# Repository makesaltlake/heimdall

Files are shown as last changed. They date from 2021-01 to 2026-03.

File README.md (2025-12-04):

# Heimdall

Heimdall is [Make Salt Lake](https://makesaltlake.org)'s member management and access control system. It consists of a few different parts:

  - [Firmware](firmware) intended to run on an [ESP32](https://en.wikipedia.org/wiki/ESP32), one per door or other device that needs access control.
  - [PCB designs](hardware) that can be used to make the physical badge readers.

### 
Join [Make Salt Lake's Slack team](https://slack.makesaltlake.org/), then head over to [#rfid-strikeforce](https://app.slack.com/client/T16JZCGBY/CGDLBCCCT) if you'd like to get in touch.

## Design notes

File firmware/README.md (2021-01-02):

ESP32 based 13.56 MHz RFID access control system
===

Components
---
See the KiCad schematics in [boards/inside_board](/boards/inside_board) and [boards/outside_board](/boards/outside_board) for the components required.<br>
The RFID reader/writer module the outside board interfaces to is the [CLEV6630ARD](https://www.nxp.com/design/development-boards/freedom-development-boards/mcu-boards/clev6630ard-nfc-frontend-clrc663-iplus-i-arduino-interface-board:BLE-NFC).

Connection Details
---

The card reader (i.e. door/machinery control) doesn't use the level converter or LCD.<br>
The card writer (i.e. badge programmer) doesn't use the LEDs, buzzer, resistors or relay.

Building
--------

Install the ESP-IDF by following the steps at https://docs.espressif.com/projects/esp-idf/en/release-v4.2/get-started/index.html#installation-step-by-step .
If you clone the esp-idf repository via Git, you should checkout the version with tag `v4.2`.

Once installed, set up your environment by running `. export.sh` (`export.bat` on Windows). Then, you can run `idf.py menuconfig` to configure the BSP (Board Support Package, or `idf.py build` to build the project.

You can upload the build to the ESP32 by running `idf.py flash`, or later `idf.py app-flash` to save the second flashing the bootloader.
To write the NVS data to flash, first edit nvs\_data.csv to fill in your WiFi SSID, WiFi password, URL, RFID Reader API key, RFID Writer API key, and the Tag Key. Then, run `gen_nvs_part.sh` (`gen_nvs_part.cmd` on Windows) to generate the binary file, followed by `write_nvs_part.sh` (`write_nvs_part.cmd` on Windows) to write that file to flash.

Run `idf.py monitor` to cause the ESP32 to reset and attach the serial console.

You can combine steps: for example `idf.py app-flash monitor` to flash the code then monitor the output.

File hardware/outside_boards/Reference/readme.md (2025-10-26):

# Reference Docs

## Antenna Design

The [NXP Antenna Tool](https://community.nxp.com/t5/NFC/bd-p/nfc) was used to
identify the component values and antenna circuit design.

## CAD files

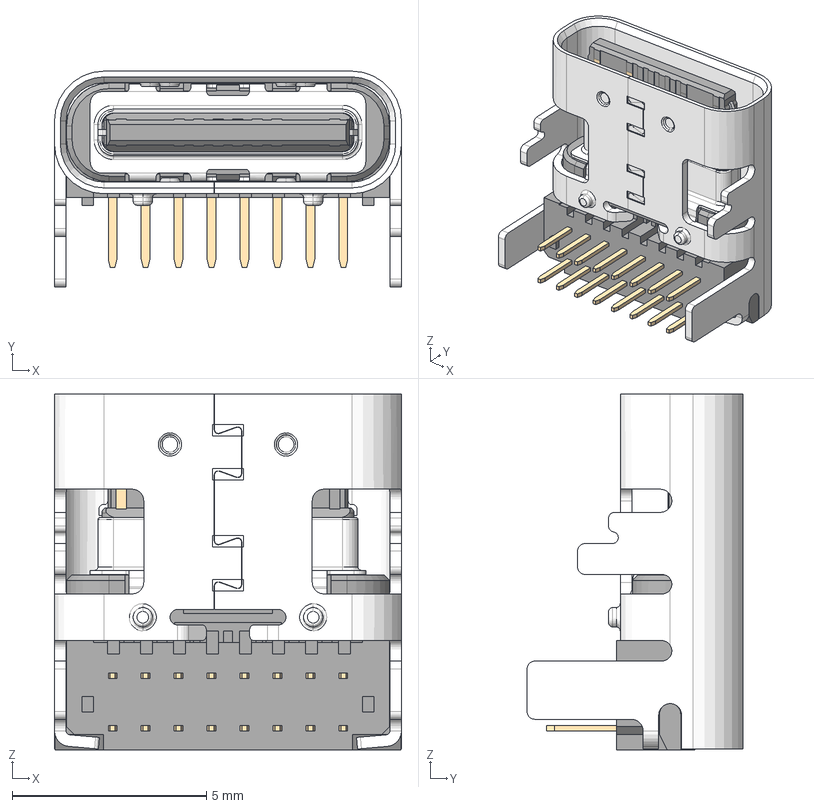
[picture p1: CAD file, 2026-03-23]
hardware/shared/cots/USB4920-00-A.stp
8.94 x 5.56 x 9.17 mm
USB4920-00-A_PART1
USB4920-00-A_PART2
USB4920-00-A_PART3
USB4920-00-A_PART4

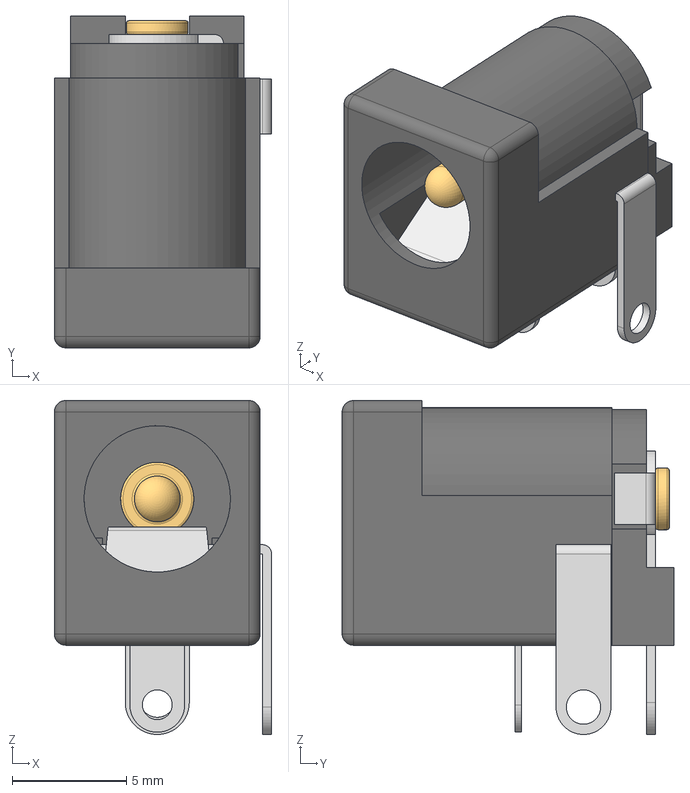
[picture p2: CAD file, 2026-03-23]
hardware/shared/cots/694106301002.stp
9.50 x 14.5 x 14.6 mm
6941xx301002
694106301002_PinContact
6941xx301002_Back
6941xx301002_PinContact2
6941xx301002_PinLame
6941xx301002_PinBis

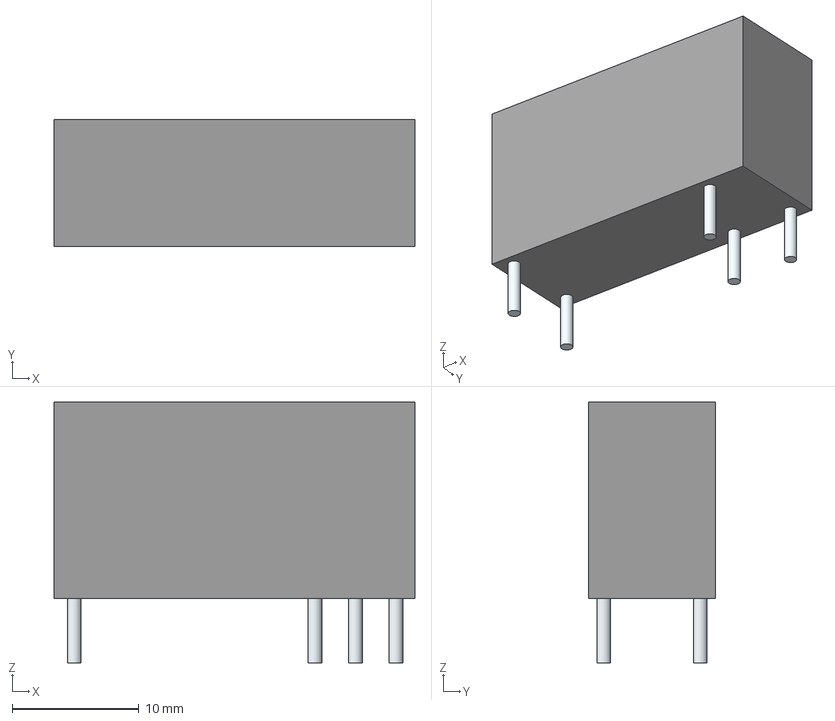
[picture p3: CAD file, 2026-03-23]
hardware/shared/cots/G6RN-17-E-ASI-CF-HA_DC5.stp
28.5 x 10.0 x 20.6 mm
Leads

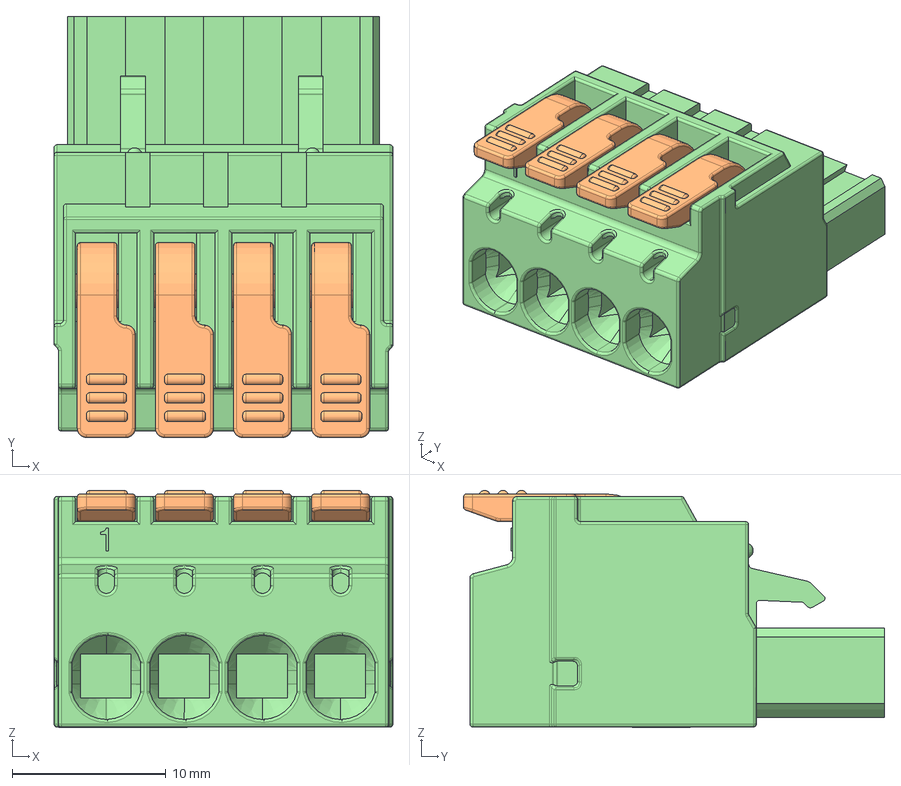
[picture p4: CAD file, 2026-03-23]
hardware/shared/cots/pxc_1110583_08_00_LPC-2-5-4-ST-5-08_3D.stp
22.0 x 27.4 x 15.4 mm

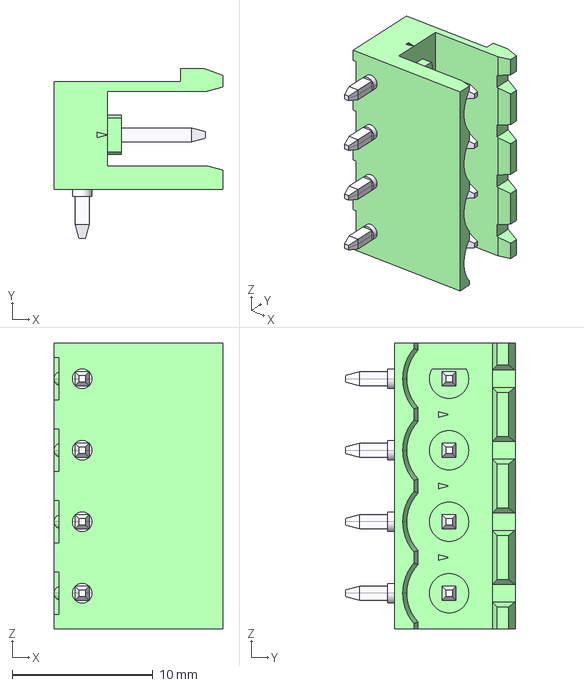
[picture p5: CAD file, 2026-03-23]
hardware/shared/cots/1759033.stp
12.0 x 12.1 x 20.3 mm

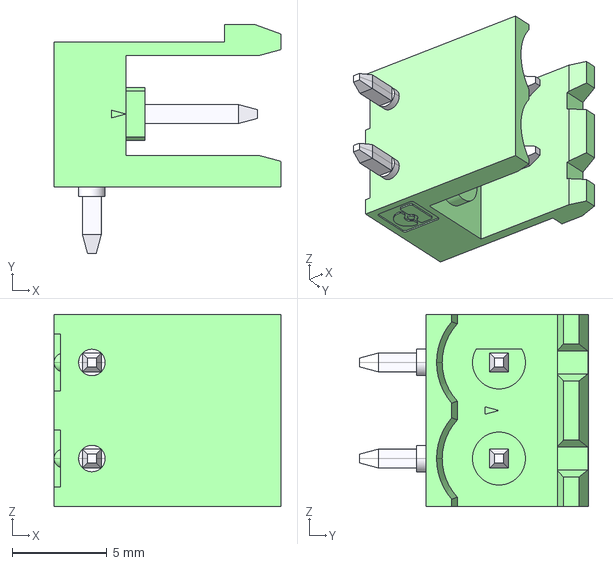
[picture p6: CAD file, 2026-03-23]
hardware/shared/cots/1759017.stp
12.0 x 12.1 x 10.2 mm

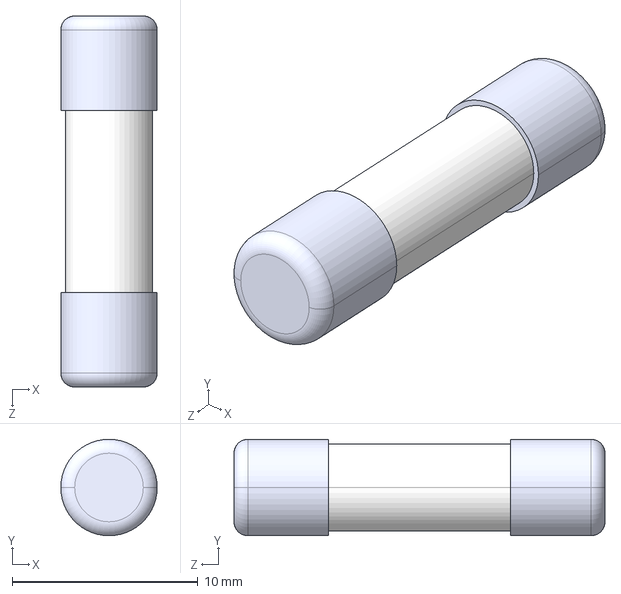
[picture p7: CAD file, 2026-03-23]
hardware/shared/cots/5x20 Fuse.stp
5.20 x 5.20 x 20.0 mm

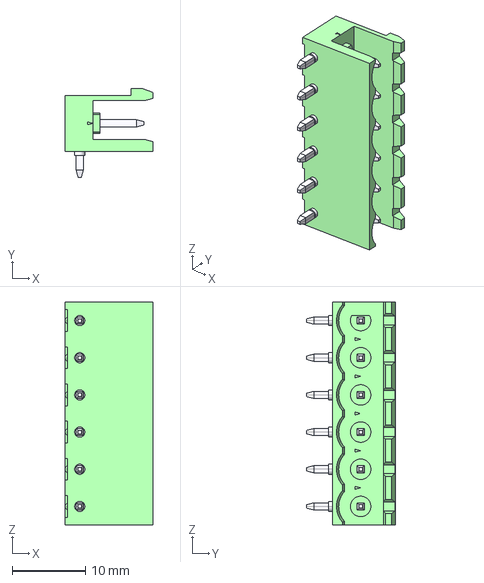
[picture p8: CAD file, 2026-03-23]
hardware/shared/cots/1759059.stp
12.0 x 12.1 x 30.5 mm

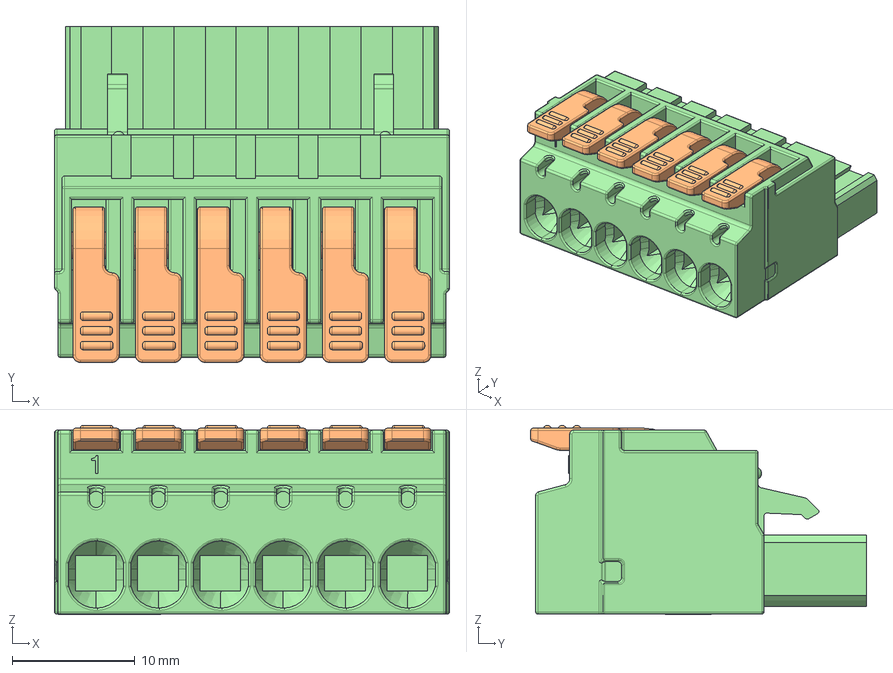
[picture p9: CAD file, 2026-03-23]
hardware/shared/cots/pxc_1110585_10_00_LPC-2-5-6-ST-5-08_3D.stp
32.2 x 27.4 x 15.4 mm

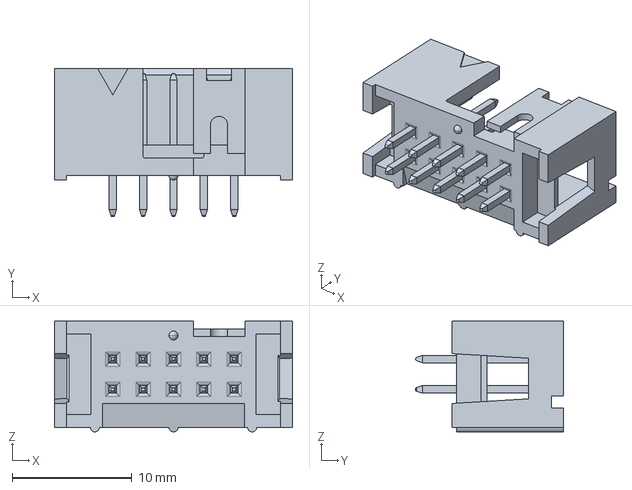
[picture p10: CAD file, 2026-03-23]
hardware/shared/cots/75869-y01c.stp
19.9 x 12.4 x 9.27 mm

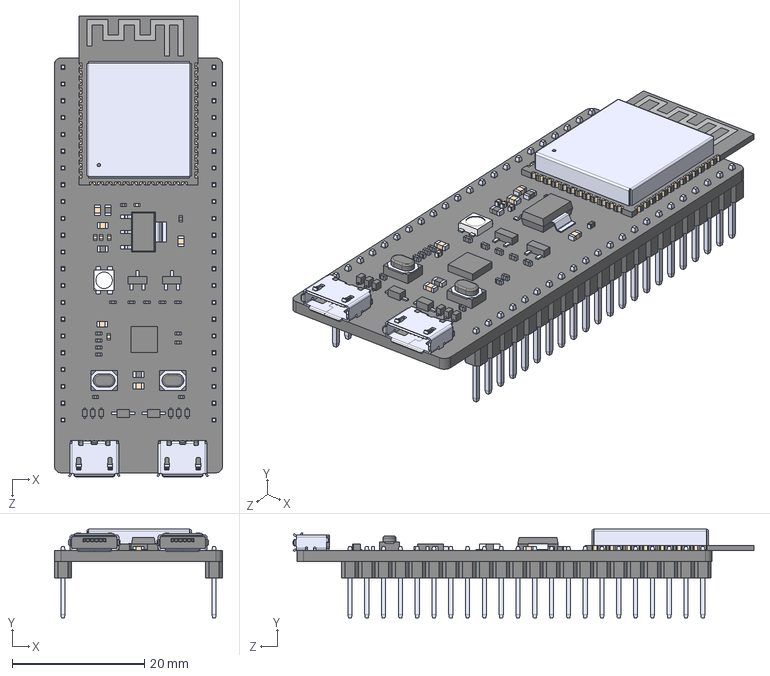
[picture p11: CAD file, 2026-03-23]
hardware/shared/cots/ESP32-S3-DEVKITC-1-N8R8.STEP
25.4 x 13.4 x 69.6 mm

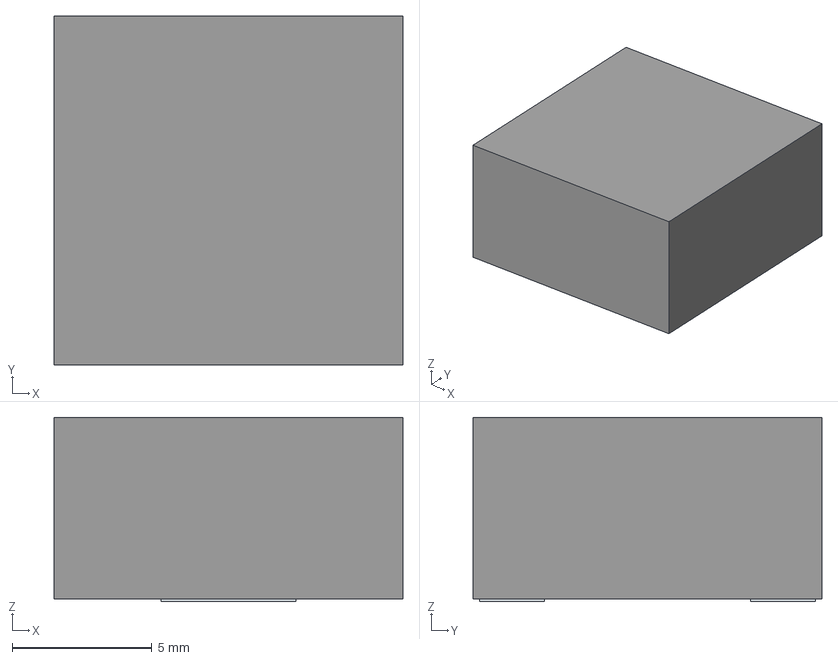
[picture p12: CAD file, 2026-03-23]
hardware/shared/cots/SRR1260A-4R7Y.stp
12.5 x 12.5 x 6.60 mm
Pins

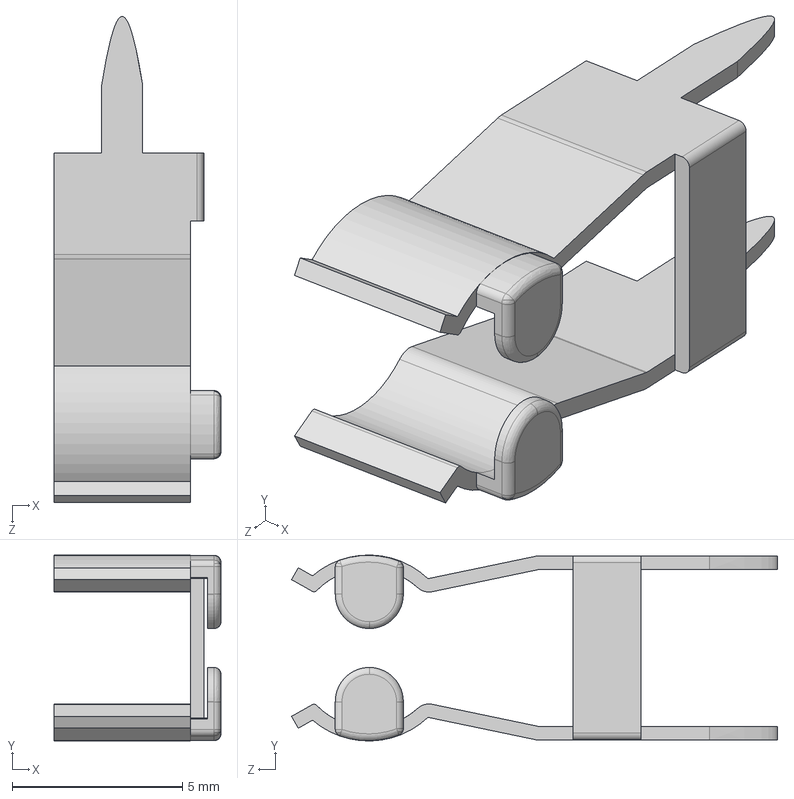
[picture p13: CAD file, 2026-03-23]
hardware/shared/cots/52100001009.stp
4.90 x 5.46 x 14.3 mm

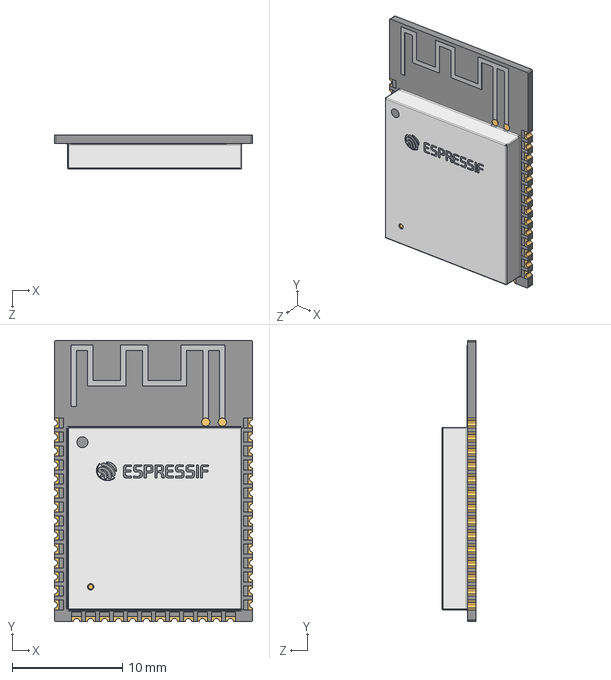
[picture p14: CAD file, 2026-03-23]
hardware/shared/cots/ESP32-S3-WROOM-1-N8R8.stp
18.0 x 25.5 x 3.10 mm

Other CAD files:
hardware/shared/cots/pxc_1110581_10_00_LPC-2-5-2-ST-5-08_3D.stp
hardware/shared/cots/CRJ024-1-TH.stp
hardware/shared/cots/1991095.stp
hardware/shared/cots/CMT-1075-SMT-TR.stp
hardware/shared/cots/43045-1019.stp
hardware/shared/cots/53398-1071.stp
hardware/shared/cots/CLRC66303HNY.stp

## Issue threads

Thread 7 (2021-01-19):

Add a badge reader/writer board firmware system

javawizard, 2021-01-19:
We need a way to allow developers to upload new firmware for the badge readers and writers and allow them to download it over-the-air and update themselves whenever it's changed.

Current thinking is to have that baked into Heimdall itself, probably in the form of something like:

- A new model, `DeviceFirmware`, that has an Active Storage attachment for a binary firmware blob
- Some way of flagging which uploaded firmware should be the current one that gets rolled out to all devices
- Some way of having different sets of firmware for badge readers and badge writers (and other devices in the future)

Open questions:

- Is there any sort of CI pipeline attached to this or is the expectation that a developer builds the firmware on their local computer and uploads it manually to Heimdall?
  - How feasible would a CI pipeline be with Espressif's SDK's requirements?
- How best to support anyone outside of Make Salt Lake who wants to deploy a Heimdall instance? It wouldn't be any good if they had to install Espressif's SDK themselves, build the firmware, and upload it to their own instance. (If CI is feasible, perhaps firmware releases could be built automatically on repo push and Heimdall could pull them in from GitHub and expose them in the UI, with the ability to also upload firmware blobs by hand in case a developer wants to test out some changes they've made locally but haven't pushed.)

bcran, 2021-01-19:
The current expectation is that developers would build the firmware on their local machine and upload it manually. But it _would_ be good to have CI to build it automatically. I'm sure it would be possible to do - I'll look into it.

I like the idea of Heimdall pulling firmware from Github and displaying it in a UI. The initial customization will always have to be locally, since without it the firmware doesn't know the WiFi SSID/password: which brings up the point of what to do if (when?) the WiFi password gets changed? Should we be able to build firmware that has the new password embedded in it, and which updates the non-volatile storage key/pair storage area?

javawizard, 2021-01-19:
@bcran I totally forgot about the WiFi credentials. That throws a wrench in the works...

Is it possible to update the NVS area programmatically from firmware without otherwise replacing the firmware itself? If so, it seems like another way to do it would be to have firmware bundles that don't embed credentials uploaded to GitHub and then have a separate, out-of-band mechanism for pushing new wireless credentials to the devices, like a separate endpoint in Heimdall, since yeah, that totally needs to be specific to a given Heimdall instance. Would that work?

javawizard, 2021-01-19:
(Not that any of this needs to be done right off the bat, of course.)

bcran, 2021-01-24:
@javawizard Yes, the way it's designed is that the NVS area is always updated separately from the firmware, using the esp-idf nvs tool on the host computer. I presume the firmware running on the device can also update that area itself.

I'm guessing we'd need to support having two sets of WiFi credentials, with the old one being tried until the new one starts working?

javawizard, 2021-01-26:
@bcran Yeah, seems like that'd be helpful when doing a switchover. (It's not strictly needed here at the space since our access points can serve multiple SSIDs at the same time, but at least from the Heimdall end it wouldn't be hard to implement.)

So in that case I'll plan to write two different systems, one to expose to badges the WiFi credentials they should use and one to expose the firmware blob they should use.

How do you want to determine if an update is needed? I could write an endpoint to fetch the SHA of the latest firmware bundle - would that be sufficient?

bcran, 2021-01-27:
The firmware has a built-in version number, so I think the ESP-IDF OTA API takes care of it.

javawizard, 2021-01-27:
Got it. Rephrase: is there anything special you'd like me to do to prevent the firmware from needing to download a full copy of the current firmware version every time it checks for an update? (Or, is the firmware small enough that that's not a problem?)

bcran, 2021-01-28:
This may be a little optimistic, but I'm presuming just the first few bytes of the firmware need downloaded to get the firmware description header and check the version.

bcran, 2021-01-28:
Otherwise, the firmware .bin file is only 800 KB, so it wouldn't be terrible if it did download it all.

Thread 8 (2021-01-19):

Spike: membership sign up and management

javawizard, 2021-01-19:
The only thing keeping MSL's WordPress instance (which costs a pretty penny to run, more than  Heimdall itself) around now that the website has been moved to makesaltlake/public_website is that it handles member signup and membership changes (like changing plans and adding card info). That's a lot of money to spend just for that.

I had a look around some time ago at other self-service recurring subscription signup and management portals and all of the options I found were even more expensive at our scale (in no small part because they tend to bill on revenue percentage) or missing features we need (like a way to log in and switch between plans).

So, given all of that and given that a lot of neat possibilities open up if members are able to sign into Heimdall (like certifiers being able to enter certifications themselves instead of Jen having to enter them manually, members being able to purchase gift cards, and Heimdall sending emails to all members certified in a given area when an access code changes), I'd like to try writing a membership signup and management system into Heimdall.

The way I'm thinking that would go down is as follows:

* Write a prototype membership signup form. It should accept all the same fields our current one does and should embed a Stripe credit card field to accept payment. It should create Stripe subscriptions but not do any other functionally useful stuff. It should also use a hardcoded plan.
* Enhance it to use multiple plans - probably hardcode them at first, but perhaps add a DB model where plans can be configured. Whether or not there should be a page to pick between plans is an open question; it may be fine to have the plan chooser live in makesaltlake/public_website and link to a page specific to each plan.
* Enhance it to support coupons. This will require investigating whether Stripe's built-in coupon support is sufficient for our needs (it wasn't for MemberPress, the WordPress plugin we currently use to manage memberships, so they implemented their own coupon system that creates plans from scratch for each new signup; it's possible we may have to do the same).
* See if anything else is missing from the existing membership signup system feature wise
* Ask MSL staff how they want the "where did you hear about us" field to work and if there's any other data they'd want to collect from new members going forward
* Wire up email sending to Heimdall in production using something like Sendgrid, SparkPost, or Mailgun. Now that SparkPost no longer offers their 10,000 emails/month free plan, MailGun's [flex plan](https://www.mailgun.com/pricing/) ($0.80/1,000 emails sent) is probably the cheapest for us considering our low volume (which I imagine will be one email receipt per month to each member, and possibly not even that since Stripe also sends receipts on our behalf).
* Configure the signup form to create users in Heindall on signup and send an email with a link to set up the user's account when created. It should only send that email when a user signs up through the form, not when a user is manually created or automatically created by signing up through the old form. There should, however, be a way to send it manually from the admin console, and it would be ideal if an already-existing user who signed up again through the form (perhaps because they cancelled a while back and are signing up again) got the email as well if they hadn't yet set a password.
* Build a page where an authenticated user can update their Stripe card info on file. It will need to do something useful if they don't have a corresponding Stripe customer yet. It will also need to do something useful if they have multiple Customers in Stripe (and we should see if and how many of such users exist).
* Build a page where an authenticated user can change their plan. We'll need to think through whether they should be able to apply a coupon when they do that (and how to limit most coupons from being used more than once by the same user).
* Build some sort of way for existing members to sign up for a Heimdall account and manage their membership there
* Do a pass through to see if there are any other member management features we need for round 1 that are missing and implement them.
* Try having a few new members we talk to on tours sign up through the new system and see how it goes for them. Make any changes needed based on their feedback.
* (Possibly consider A/B testing the new signup form vs the old one to make sure there isn't a notable decrease in conversions, and make any changes needed to address that if there is)
* Roll out the new system to all new member signups
* Put a note on the old WordPress system directing users to the new system (but leave the old one running for a bit)
* Announce the new system to the membership somewhere
* After some time, sunset the old system and possibly consider moving/aliasing Heimdall to membership.makesaltlake.org

javawizard, 2021-01-19:
One important note: however member signup and management is implemented, it needs to be easy to replace the system with an off-the-shelf system on short notice should all of us developers get hit by a bus (even if it costs more than we'd like). The last thing we want to do is get into a situation where years down the road Heimdall dies, no-one's around to fix it, and we can't sign members up as a result.

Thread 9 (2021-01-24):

Add a way to filter users by those who have a certain discount applied

javawizard, 2021-01-24:
This is per a request from Jen, though I can't find the source at the moment - we would like to be able to view users who have a particular discount applied at the current moment.

This may be tricker than it sounds, because MemberPress creates oneoff Stripe plans for each user and doesn't appear to expose to Stripe which MemberPress-side discount was applied when the user signed up. We may need to talk to MemberPress's API to do that...

...and, given #8, it's debatable whether we should do that now or whether we should wait a bit to see if we're able to do #8 and import all subscriptions, including MemberPress discount data, into Heimdall and save ourselves some trouble.

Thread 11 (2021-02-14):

Switch the Synchrotron reporter to use information from the Subscription model to compute its data

javawizard, 2021-02-14:
That will allow the synchrotron reporter to report instantly without having to iterate through all Stripe subscriptions via Stripe's API each time it's about to post.

It will also make #10 easier to implement since we can detect if the subscription in question already has `unpaid` set to `true` - in which case there's no need to re-notify about a failed payment.

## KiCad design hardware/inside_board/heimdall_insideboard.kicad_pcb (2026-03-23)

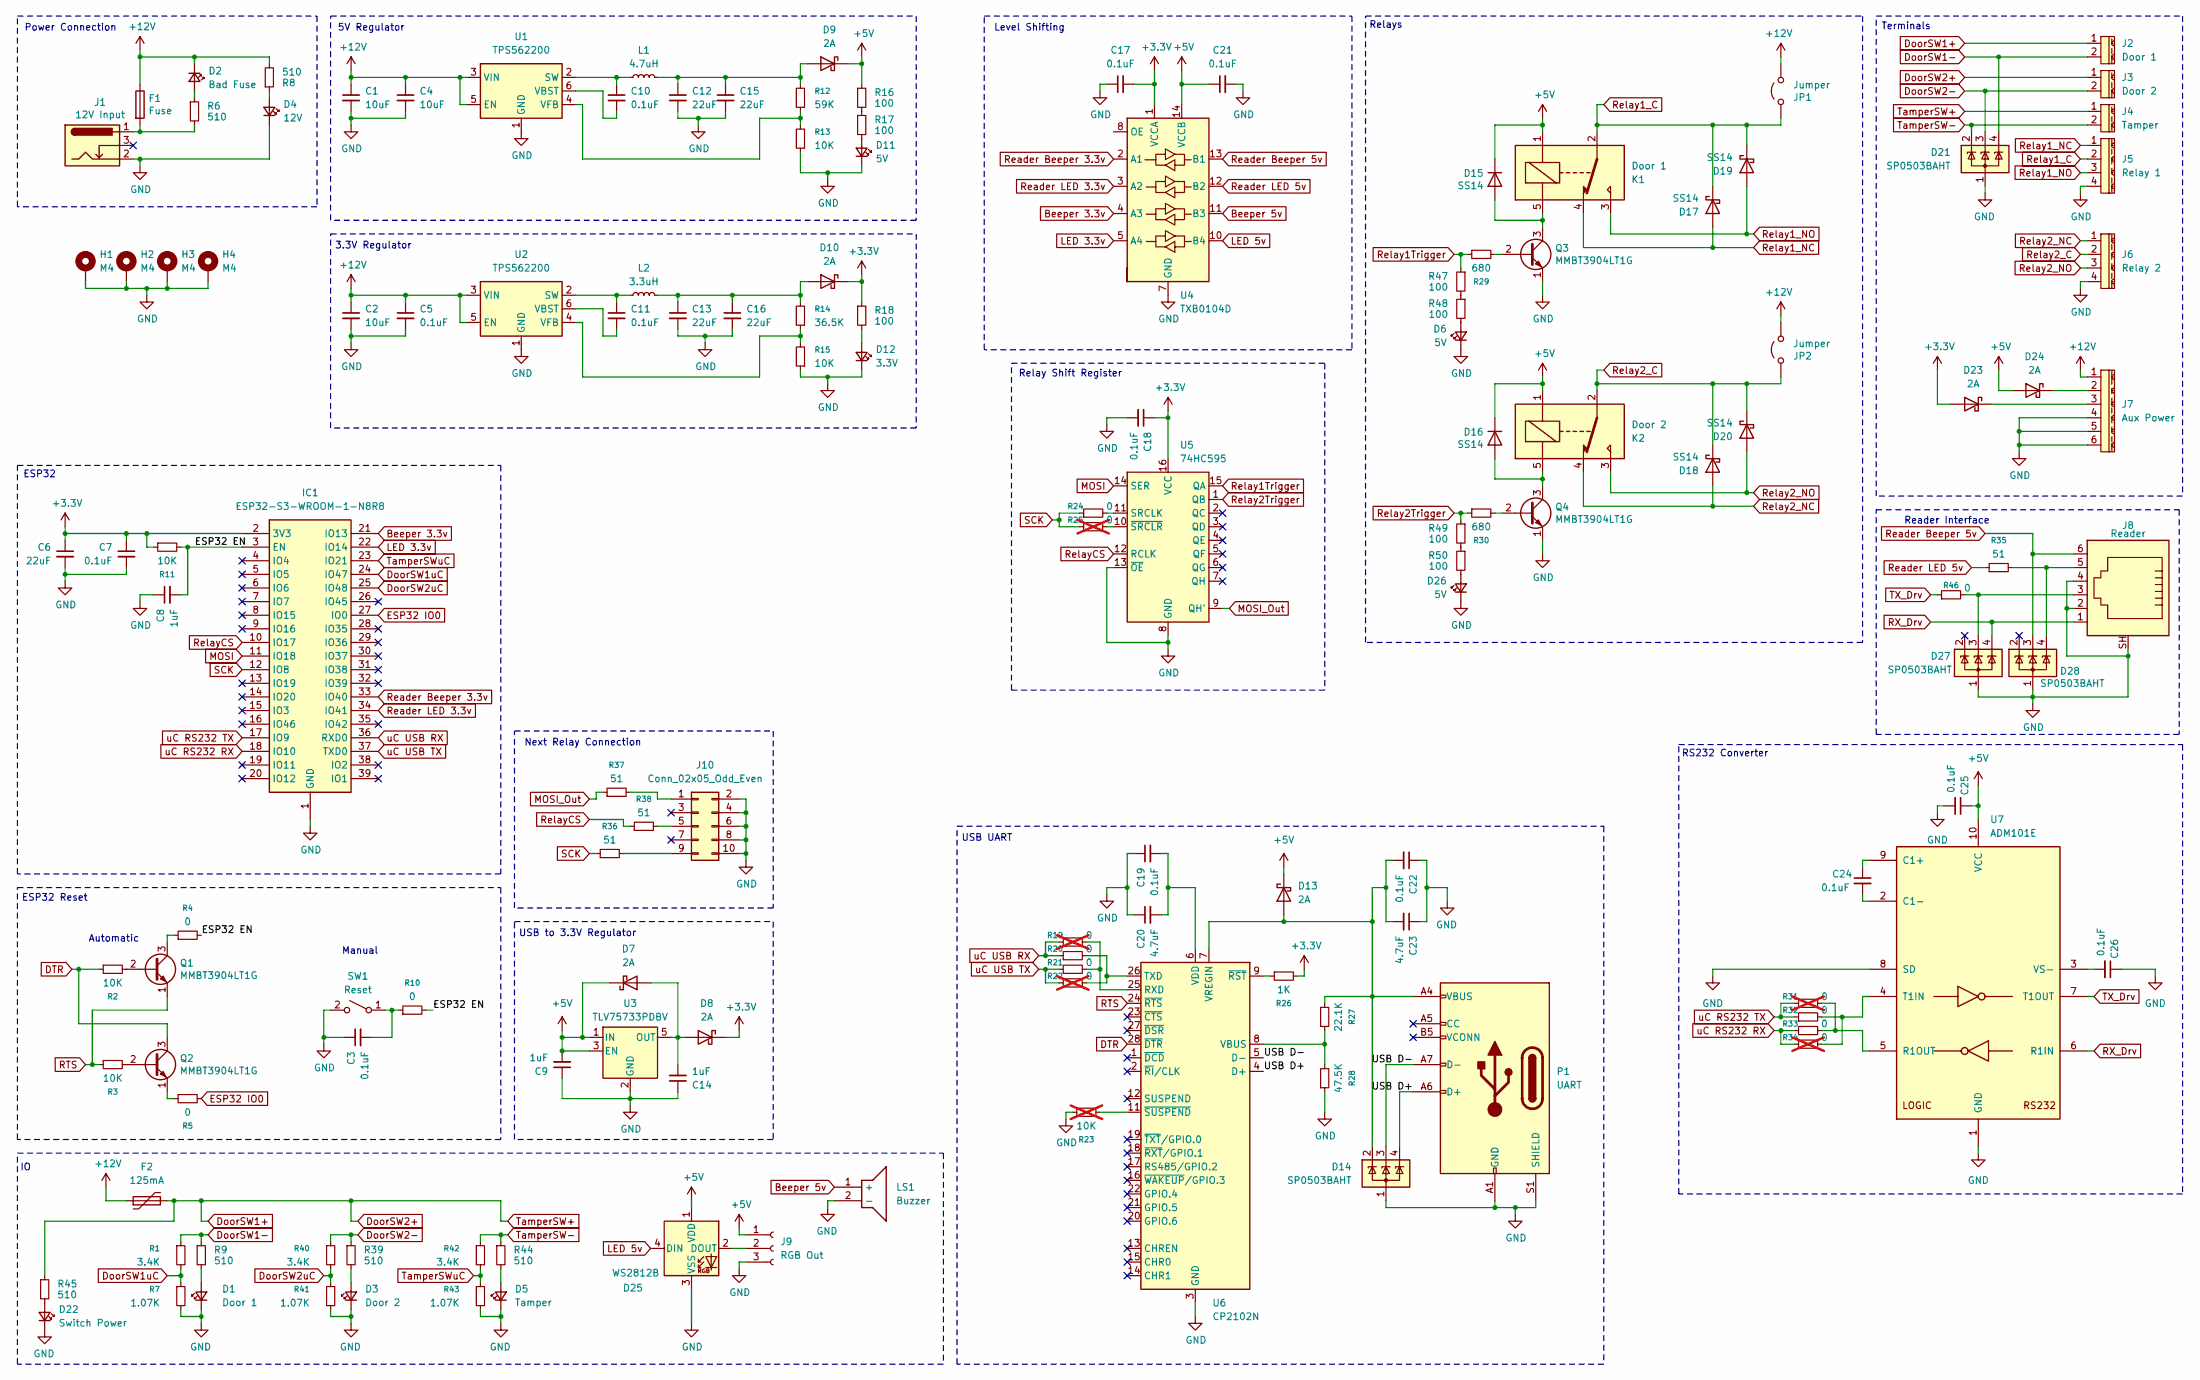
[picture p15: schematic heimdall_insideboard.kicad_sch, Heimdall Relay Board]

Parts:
C1, C2, C4: 10uF; C_0805_2012Metric
C3, C5, C7, C10, C11, C17, C18, C19, C21, C22, C24, C25, C26: 0.1uF; C_0805_2012Metric
C6, C12, C13, C15, C16: 22uF; C_0805_2012Metric
C8, C9, C14: 1uF; C_0805_2012Metric
C20, C23: 4.7uF; C_0805_2012Metric
D1: Door 1; LED_0805_2012Metric
D2: Bad Fuse; LED_0805_2012Metric
D3: Door 2; LED_0805_2012Metric
D4: 12V; LED_0805_2012Metric
D5: Tamper; LED_0805_2012Metric
D6, D11, D26: 5V; LED_0805_2012Metric
D7, D8, D9, D10, D13, D23, D24: 2A; D_SMB
D12: 3.3V; LED_0805_2012Metric
D14, D21, D27, D28: SP0503BAHT; SOT-143
D15, D16, D17, D18, D19, D20: SS14; D_SMA
D22: Switch Power; LED_0805_2012Metric
D25: WS2812B; LED_WS2812B_PLCC4_5.0x5.0mm_P3.2mm
F1: Fuse; Fuseholder_Clip-5x20mm_Littelfuse_521_Lateral_P17.00x5.00mm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
F2: 125mA; Fuse_1206_3216Metric
H1, H2, H3, H4: M4; MountingHole_4.3mm_M4_Pad_Via
IC1: ESP32-S3-WROOM-1-N8R8; ESP32S3WROOM1N8R8; Mouser Part Number 356-EP32S3WROOM1N8R8
J1: 12V Input; BarrelJack_Wuerth_6941xx301002
J2: Door 1; 1759017
J3: Door 2; 1759017
J4: Tamper; 1759017
J5: Relay 1; 1759033
J6: Relay 2; 1759033
J7: Aux Power; 1759059
J8: Reader; CRJ0241TH
J9: RGB Out; PinHeader_1x03_P2.54mm_Vertical
J10: Conn_02x05_Odd_Even; 75869-101LF
JP1, JP2: Jumper; PinHeader_1x03_P2.54mm_Vertical
K1: Door 1; G6RN17EASICFHADC5; Manufacturer_Part_Number G6RN-17-E-ASI-CF-HA DC5
K2: Door 2; G6RN17EASICFHADC5; Manufacturer_Part_Number G6RN-17-E-ASI-CF-HA DC5
L1: 4.7uH; SRR1260A4R7Y
L2: 3.3uH; SRR1260A4R7Y
LS1: Buzzer; CMT1075SMTTR; Mouser Part Number 490-CMT-1075-SMT-TR
P1: UART; USB4920-00-A
Q1, Q2, Q3, Q4: MMBT3904LT1G; SOT-23-3
R1, R40, R42: 3.4K; R_0805_2012Metric
R2, R3, R11, R13, R15: 10K; R_0805_2012Metric
R4, R5, R10, R20, R21, R24, R32, R33, R46: 0; R_0805_2012Metric
R6, R8, R9, R39, R44, R45: 510; R_0805_2012Metric
R7, R41, R43: 1.07K; R_0805_2012Metric
R12: 59K; R_0805_2012Metric
R14: 36.5K; R_0805_2012Metric
R16, R17, R18, R47, R48, R49, R50: 100; R_0805_2012Metric
R19, R22, R25, R31, R34: 0; R_0805_2012Metric; not fitted
R23: 10K; R_0805_2012Metric; not fitted
R26: 1K; R_0805_2012Metric
R27: 22.1K; R_0805_2012Metric
R28: 47.5K; R_0805_2012Metric
R29, R30: 680; R_0805_2012Metric
R35, R36, R37, R38: 51; R_0805_2012Metric
SW1: Reset; SW_SPST_Omron_B3FS-100xP
U1, U2: TPS562200; SOT-23-6
U3: TLV75733PDBV; SOT-23-5
U4: TXB0104D; SOIC-14_3.9x8.7mm_P1.27mm
U5: 74HC595; SOIC-16W_7.5x10.3mm_P1.27mm
U6: CP2102N; QFN-28-1EP_5x5mm_P0.5mm_EP3.35x3.35mm
U7: ADM101E; MSOP-10_3x3mm_P0.5mm

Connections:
+3.3V: C6.1, C7.1, C17.2, C18.1, D8.1 (K), D10.1 (K), D23.2 (A), IC1.2 (3V3), R11.1, R18.1, R26.2, U4.1 (VCCA), U5.16 (VCC)
+5V: C9.2, C21.1, C25.1, D7.1 (K), D9.1 (K), D13.1 (K), D15.1 (K), D16.1 (K), D24.2 (A), D25.1 (VDD), J9.1, K1.1, K2.1, R16.1, U3.1 (IN), U3.3 (EN), U4.14 (VCCB), U7.10 (VCC)
+12V: C1.1, C2.1, C4.1, C5.1, D2.1 (K), F1.1, F2.1, J7.1, JP1.1 (A), JP2.1 (A), R8.2, U1.3 (VIN), U1.5 (EN), U2.3 (VIN), U2.5 (EN)
/ESP32 EN: C8.2, IC1.3 (EN), R4.2, R10.2, R11.2
/USB D+: D14.4 (K), P1.A6 (D+), U6.4 (D+)
/USB D-: D14.3 (K), P1.A7 (D-), U6.5 (D-)
Beeper 3.3v: IC1.21 (IO13), U4.4 (A3)
Beeper 5v: LS1.1 (+), U4.11 (B3)
DTR: Q2.3 (C), R2.1, U6.28 (~DTR)
DoorSW1+: F2.2, J2.1, J3.1, J4.1, R45.1
DoorSW1-: D21.4 (K), J2.2, R1.1, R9.1
DoorSW1uC: IC1.24 (IO47), R1.2, R7.1
DoorSW2-: D21.3 (K), J3.2, R39.1, R40.1
DoorSW2uC: IC1.25 (IO48), R40.2, R41.1
ESP32 IO0: IC1.27 (IO0), R5.2
GND: C1.2, C2.2, C3.1, C4.2, C5.2, C6.2, C7.2, C8.1, C9.1, C12.2, C13.2, C14.1, C15.2, C16.2, C17.1, C18.2, C19.1, C20.1, C21.2, C22.1, C23.1, C25.2, C26.1, D1.1 (K), D3.1 (K), D4.1 (K), D5.1 (K), D6.1 (K), D11.1 (K), D12.1 (K), D14.1 (A), D21.1 (A), D22.1 (K), D25.3 (VSS), D26.1 (K), D27.1 (A), D28.1 (A), H1.1, H2.1, H3.1, H4.1, IC1.1 (GND), J1.2, J5.4, J6.4, J7.4, J7.5, J7.6, J8.2, J8.4, J8.SH, J9.3, J10.2, J10.4, J10.6, J10.8, J10.10, LS1.2 (-), P1.A1 (GND), P1.A12 (GND), P1.B1 (GND), P1.B12 (GND), P1.S1 (SHIELD), Q3.1 (E), Q4.1 (E), R7.2, R13.1, R15.1, R23.1, R28.1, R41.2, R43.2, SW1.2 (B), U1.1 (GND), U2.1 (GND), U3.2 (GND), U4.7 (GND), U5.8 (GND), U5.13 (~OE), U6.3 (GND), U6.29 (GND), U7.1 (GND), U7.8 (SD)
LED 3.3v: IC1.22 (IO14), U4.5 (A4)
LED 5v: D25.4 (DIN), U4.10 (B4)
MOSI: IC1.11 (IO18), U5.14 (SER)
MOSI_Out: R37.1, U5.9 (QH')
unnamed: D1.2 (A), R9.2
unnamed: D2.2 (A), R6.1
unnamed: D3.2 (A), R39.2
unnamed: D4.2 (A), R8.1
unnamed: D5.2 (A), R44.2
unnamed: D6.2 (A), R48.2
unnamed: C14.2, D7.2 (A), D8.2 (A), U3.5 (OUT)
unnamed: C12.1, C15.1, D9.2 (A), L1.2, R12.2
unnamed: C13.1, C16.1, D10.2 (A), L2.2, R14.2
unnamed: D11.2 (A), R17.2
unnamed: D12.2 (A), R18.2
unnamed: C22.2, C23.2, D13.2 (A), D14.2 (K), P1.A4 (VBUS), P1.A9 (VBUS), P1.B4 (VBUS), P1.B9 (VBUS), R27.2, U6.7 (VREGIN)
unnamed: D15.2 (A), K1.5, Q3.3 (C)
unnamed: D16.2 (A), K2.5, Q4.3 (C)
unnamed: D22.2 (A), R45.2
unnamed: D23.1 (K), J7.3
unnamed: D24.1 (K), J7.2
unnamed: D25.2 (DOUT), J9.2
unnamed: D26.2 (A), R50.2
unnamed: D27.3 (K), J8.3, R46.2
unnamed: D28.4 (K), J8.5, R35.2
unnamed: F1.2, J1.1, R6.2
unnamed: J10.1, R37.2
unnamed: J10.5, R38.2
unnamed: J10.9, R36.2
unnamed: Q1.2 (B), R2.2
unnamed: Q1.3 (C), R4.1
unnamed: Q2.2 (B), R3.2
unnamed: Q2.1 (E), R5.1
unnamed: Q3.2 (B), R29.2
unnamed: Q4.2 (B), R30.2
unnamed: R16.2, R17.1
unnamed: R47.2, R48.1
unnamed: R49.2, R50.1
unnamed: C3.2, R10.1, SW1.1 (A)
unnamed: C10.1, L1.1, U1.2 (SW)
unnamed: C10.2, U1.6 (VBST)
unnamed: R12.1, R13.2, U1.4 (VFB)
unnamed: C11.1, L2.1, U2.2 (SW)
unnamed: C11.2, U2.6 (VBST)
unnamed: R14.1, R15.2, U2.4 (VFB)
unnamed: R24.2, U5.11 (SRCLK)
unnamed: R25.2, U5.10 (~SRCLR)
unnamed: R19.2, R21.2, U6.25 (RXD)
unnamed: R20.2, R22.2, U6.26 (TXD)
unnamed: R27.1, R28.2, U6.8 (VBUS)
unnamed: C19.2, C20.2, U6.6 (VDD)
unnamed: R26.1, U6.9 (~RST)
unnamed: R23.2, U6.11 (~SUSPEND)
unnamed: C24.1, U7.9 (C1+)
unnamed: C24.2, U7.2 (C1-)
unnamed: R31.2, R33.2, U7.5 (R1OUT)
unnamed: R32.2, R34.2, U7.4 (T1IN)
unnamed: C26.2, U7.3 (VS-)
RTS: Q1.1 (E), R3.1, U6.24 (~RTS)
RX_Drv: D27.4 (K), J8.1, U7.6 (R1IN)
Reader Beeper 3.3v: IC1.33 (IO40), U4.2 (A1)
Reader Beeper 5v: D28.3 (K), J8.6, U4.13 (B1)
Reader LED 3.3v: IC1.34 (IO41), U4.3 (A2)
Reader LED 5v: R35.1, U4.12 (B2)
Relay1Trigger: R29.1, R47.1, U5.15 (QA)
Relay1_C: D17.1 (K), D19.1 (K), J5.2, JP1.2 (B), K1.2
Relay1_NC: D17.2 (A), J5.1, K1.4
Relay1_NO: D19.2 (A), J5.3, K1.3
Relay2Trigger: R30.1, R49.1, U5.1 (QB)
Relay2_C: D18.1 (K), D20.1 (K), J6.2, JP2.2 (B), K2.2
Relay2_NC: D18.2 (A), J6.1, K2.4
Relay2_NO: D20.2 (A), J6.3, K2.3
RelayCS: IC1.10 (IO17), R38.1, U5.12 (RCLK)
SCK: IC1.12 (IO8), R24.1, R25.1, R36.1
TX_Drv: R46.1, U7.7 (T1OUT)
TamperSW-: D21.2 (K), J4.2, R42.1, R44.1
TamperSWuC: IC1.23 (IO21), R42.2, R43.1
uC RS232 RX: IC1.18 (IO10), R33.1, R34.1
uC RS232 TX: IC1.17 (IO9), R31.1, R32.1
uC USB RX: IC1.36 (RXD0), R19.1, R20.1
uC USB TX: IC1.37 (TXD0), R21.1, R22.1

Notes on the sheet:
Power Connection
Relay Shift Register
Automatic
RS232 Converter
ESP32 Reset
USB to 3.3V Regulator
Terminals
Next Relay Connection
Manual
3.3V Regulator
5V Regulator
Reader Interface
Relays
Level Shifting
USB UART
ESP32

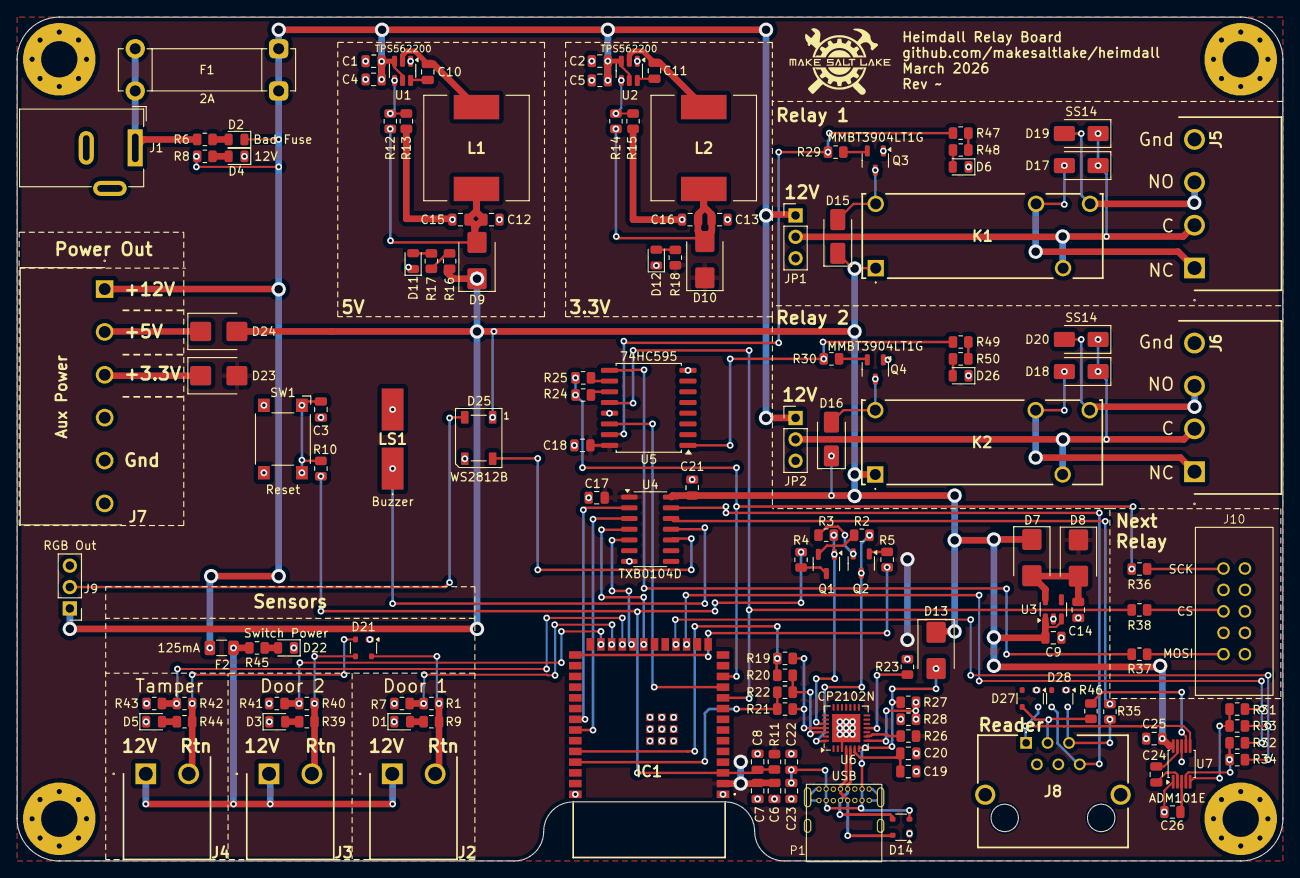
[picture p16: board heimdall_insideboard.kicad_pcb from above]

Board: 2 copper layers, 150.0 x 100.0 mm, 141 parts (0 on the bottom side), 97 nets.

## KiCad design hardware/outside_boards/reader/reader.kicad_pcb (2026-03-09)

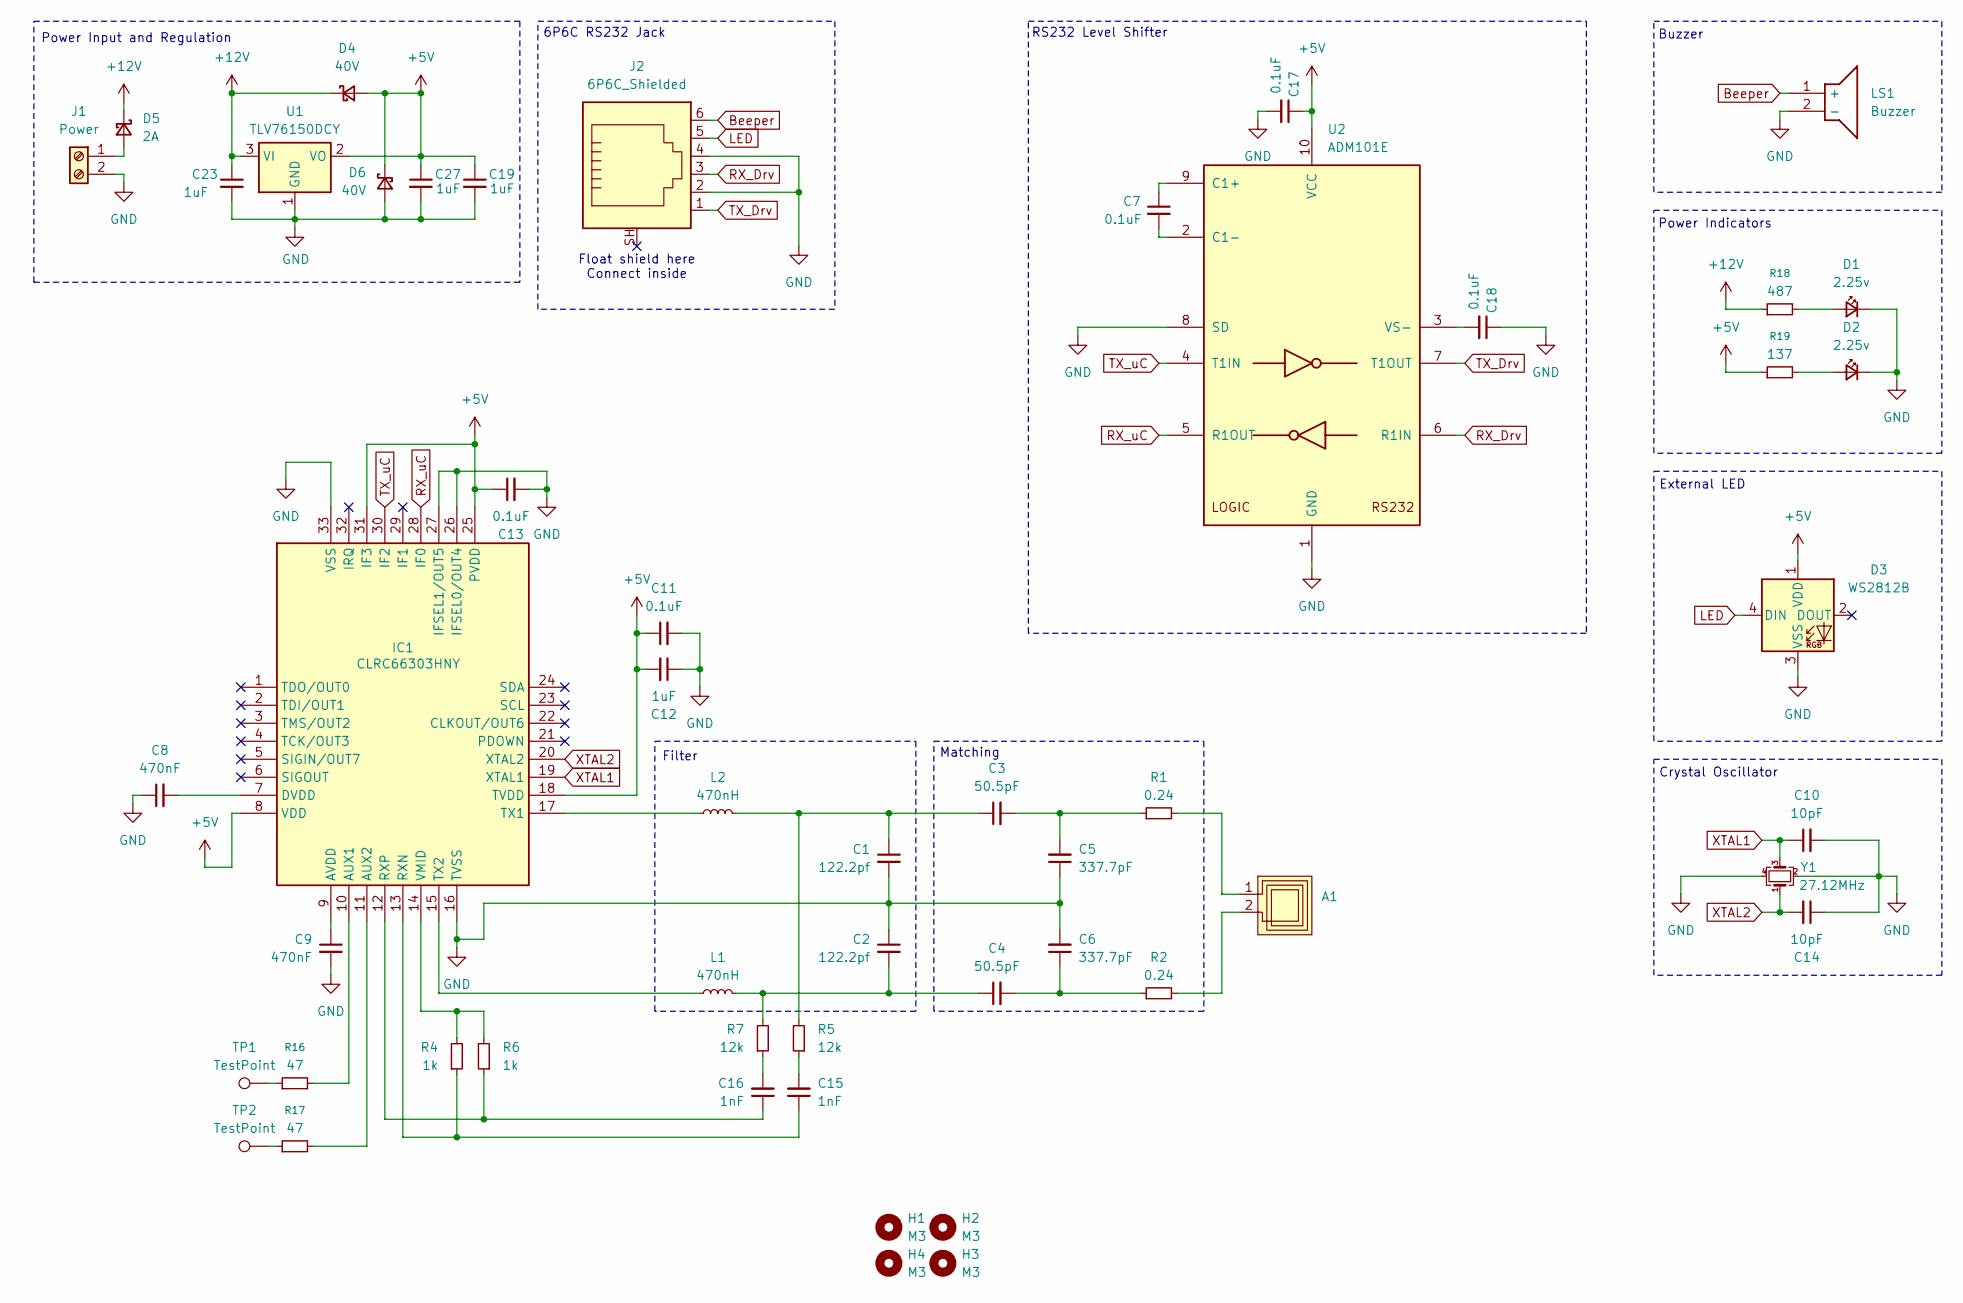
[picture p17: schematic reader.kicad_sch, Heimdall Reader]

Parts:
A1: Anetnna_50x50
C1, C2: 122.2pf; C_0805_2012Metric
C3, C4: 50.5pF; C_0805_2012Metric
C5, C6: 337.7pF; C_0805_2012Metric
C7, C11, C13, C17, C18: 0.1uF; C_0805_2012Metric
C8, C9: 470nF; C_0805_2012Metric
C10, C14: 10pF; C_0805_2012Metric
C12, C19, C23, C27: 1uF; C_0805_2012Metric
C15, C16: 1nF; C_0805_2012Metric
D1, D2: 2.25v; LED_0805_2012Metric
D3: WS2812B; LED_WS2812B_PLCC4_5.0x5.0mm_P3.2mm
D4, D6: 40V; D_1206_3216Metric
D5: 2A; D_1206_3216Metric
H1, H2, H3, H4: M3; MountingHole_3.2mm_M3
IC1: CLRC66303HNY; QFN50P500X500X100-33N; Mouser Part Number 771-CLRC66303HNY
J1: Power; 1991095
J2: 6P6C_Shielded; CRJ0241TH
L1, L2: 470nH; L_0805_2012Metric
LS1: Buzzer; CMT1075SMTTR; Mouser Part Number 490-CMT-1075-SMT-TR
R1, R2: 0.24; R_0805_2012Metric
R4, R6: 1k; R_0805_2012Metric
R5, R7: 12k; R_0805_2012Metric
R16, R17: 47; R_0805_2012Metric
R18: 487; R_0805_2012Metric
R19: 137; R_0805_2012Metric
TP1, TP2: TestPoint; TestPoint_Pad_D1.5mm
U1: TLV76150DCY; SOT-223-3_TabPin2
U2: ADM101E; MSOP-10_3x3mm_P0.5mm
Y1: 27.12MHz; Crystal_SMD_3225-4Pin_3.2x2.5mm

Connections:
+5V: C11.1, C12.2, C13.1, C17.1, C19.1, C27.1, D3.1 (VDD), D4.2 (A), D6.1 (K), IC1.8 (VDD), IC1.18 (TVDD), IC1.25 (PVDD), IC1.31 (IF3), R19.1, U1.2 (VO), U2.10 (VCC)
+12V: C23.1, D4.1 (K), D5.1 (K), R18.1, U1.3 (VI)
Beeper: J2.6, LS1.1 (+)
GND: C1.2, C2.1, C5.1, C6.2, C8.1, C9.2, C10.2, C11.2, C12.1, C13.2, C14.1, C17.2, C18.1, C19.2, C23.2, C27.2, D1.1 (K), D2.1 (K), D3.3 (VSS), D6.2 (A), IC1.16 (TVSS), IC1.26 (IFSEL0/OUT4), IC1.27 (IFSEL1/OUT5), IC1.33 (VSS), J1.2, J2.2, J2.4, LS1.2 (-), U1.1 (GND), U2.1 (GND), U2.8 (SD), Y1.2, Y1.4
LED: D3.4 (DIN), J2.5
unnamed: A1.1, R1.2
unnamed: A1.2, R2.2
unnamed: C1.1, C3.1, L2.2, R5.2
unnamed: C2.2, C4.1, L1.2, R7.2
unnamed: C3.2, C5.2, R1.1
unnamed: C4.2, C6.1, R2.1
unnamed: C15.2, R5.1
unnamed: C16.2, R7.1
unnamed: D1.2 (A), R18.2
unnamed: D2.2 (A), R19.2
unnamed: D5.2 (A), J1.1
unnamed: IC1.10 (AUX1), R16.2
unnamed: IC1.11 (AUX2), R17.2
unnamed: C9.1, IC1.9 (AVDD)
unnamed: C8.2, IC1.7 (DVDD)
unnamed: C15.1, IC1.13 (RXN), R4.1
unnamed: C16.1, IC1.12 (RXP), R6.1
unnamed: IC1.17 (TX1), L2.1
unnamed: IC1.15 (TX2), L1.1
unnamed: IC1.14 (VMID), R4.2, R6.2
unnamed: R16.1, TP1.1
unnamed: R17.1, TP2.1
unnamed: C7.1, U2.9 (C1+)
unnamed: C7.2, U2.2 (C1-)
unnamed: C18.2, U2.3 (VS-)
RX_Drv: J2.3, U2.6 (R1IN)
RX_uC: IC1.28 (IF0), U2.5 (R1OUT)
TX_Drv: J2.1, U2.7 (T1OUT)
TX_uC: IC1.30 (IF2), U2.4 (T1IN)
XTAL1: C10.1, IC1.19 (XTAL1), Y1.3
XTAL2: C14.2, IC1.20 (XTAL2), Y1.1

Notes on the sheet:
External LED
Crystal Oscillator
Power Indicators
Matching
Float shield here Connect inside
Buzzer
6P6C RS232 Jack
Power Input and Regulation
RS232 Level Shifter
Filter

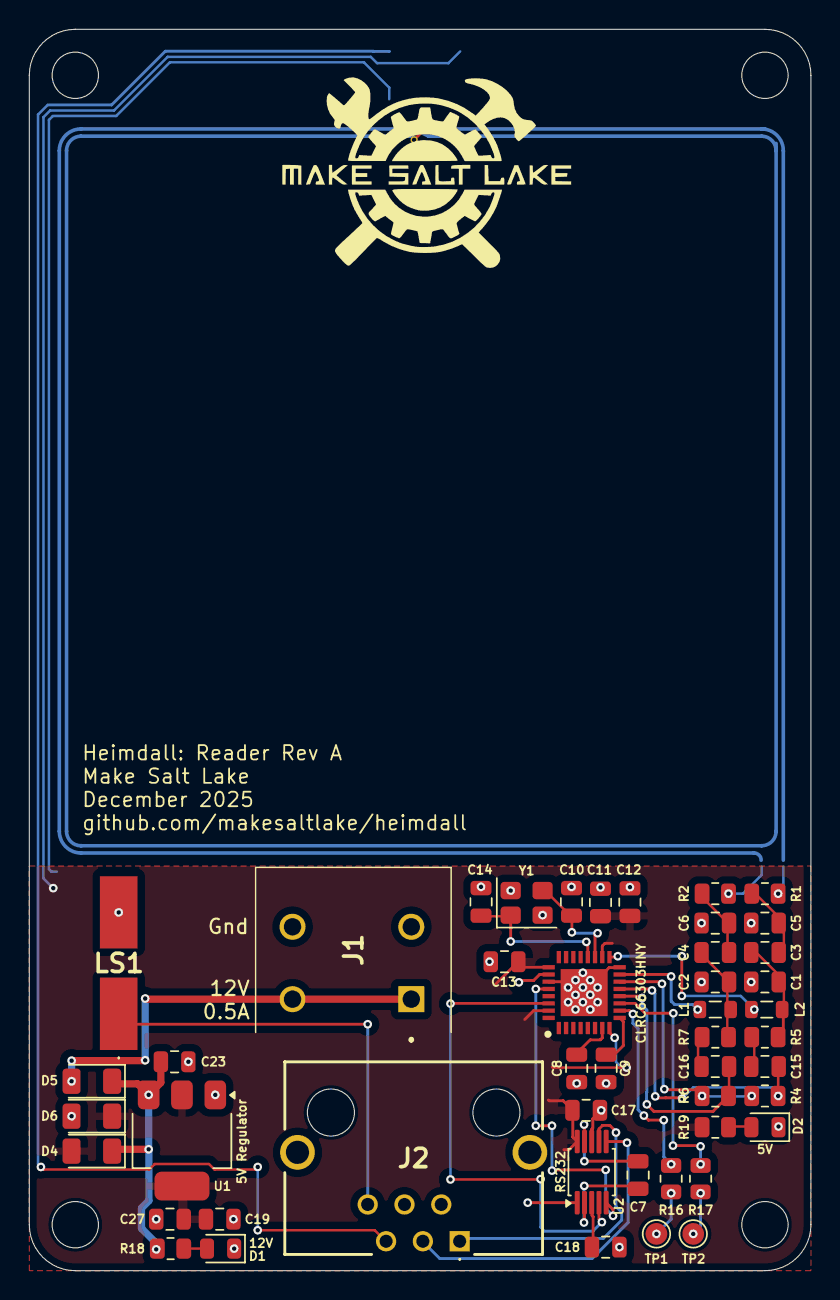
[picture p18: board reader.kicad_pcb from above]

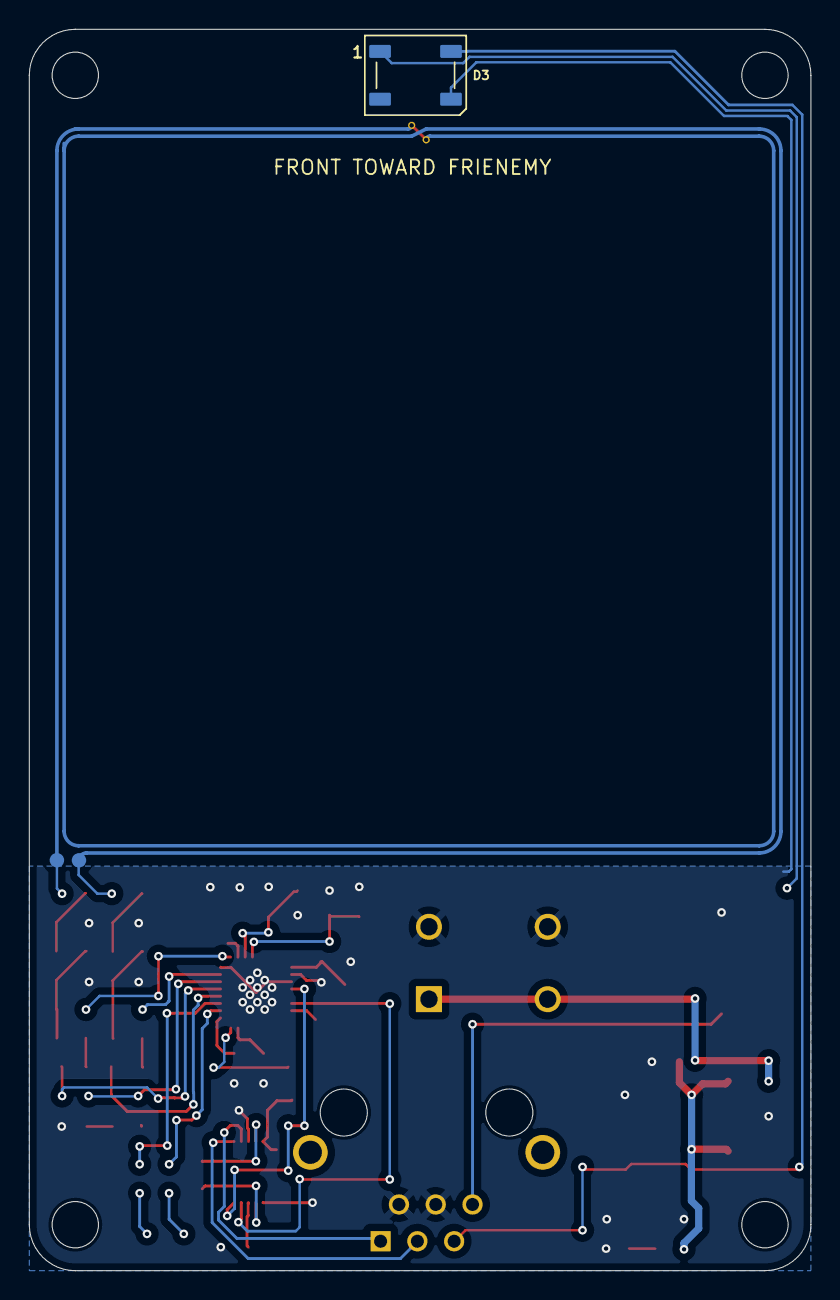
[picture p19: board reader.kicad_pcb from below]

Board: 2 copper layers, 54.0 x 85.7 mm, 53 parts (2 on the bottom side), 36 nets.

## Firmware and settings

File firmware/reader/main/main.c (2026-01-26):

/*
 * Copyright (C) 2020 Rebecca Cran <rebecca@bsdio.com>.
 *
 */

#include <string.h>
#include <unistd.h>
#include <stdio.h>

#include <freertos/FreeRTOS.h>
#include <freertos/task.h>
#include <freertos/event_groups.h>

#include <cJSON.h>
#include <esp_system.h>
#include <esp_event.h>
#include <nvs_flash.h>
#include <esp_log.h>

#include <driver/ledc.h>
#include <soc/ledc_reg.h>
#include <hal/ledc_types.h>

#include <esp_vfs_fat.h>
#include <diskio_wl.h>
#include <esp_vfs.h>

#include "clrc663.h"
#include "iso14443.h"
#include "mifare_classic.h"
#include "tag.h"
#include "network.h"
#include "../ESP32-NeoPixel-WS2812-RMT/ws2812_control.h"


static const char* TAG = "heimdall";

const int LED_GPIO_PIN = 22;
const int BUZZER_GPIO_PIN = 23;
const int RELAY1_GPIO_PIN = 17;
const int RELAY2_GPIO_PIN = 16;
const int RELAY3_GPIO_PIN = 4;
const int TAMPER_SWITCH_GPIO_PIN = 18;

const int RFID_CS_GPIO_PIN = 32;
const int CAM_CS_GPIO_PIN = 15;

extern char *heimdall_host;
extern char *reader_api_key;
extern char *writer_api_key;

char *tag_key = NULL;

cJSON *access_list = NULL;

extern char *wifi_ssid;
extern char *wifi_password;

static void set_buzzer_duty(uint32_t duty)
{
    ledc_set_duty(LEDC_LOW_SPEED_MODE, LEDC_CHANNEL_0, duty);
    ledc_update_duty(LEDC_LOW_SPEED_MODE, LEDC_CHANNEL_0);
}

static void heimdall_setup_buzzer(void)
{
    // Configure the buzzer
//    const ledc_timer_config_t buzzer_timer = {LEDC_LOW_SPEED_MODE, {LEDC_TIMER_10_BIT}, LEDC_TIMER_0, 2670, LEDC_AUTO_CLK};
//    const ledc_channel_config_t channel = {BUZZER_GPIO_PIN, LEDC_LOW_SPEED_MODE, LEDC_CHANNEL_0, LEDC_INTR_DISABLE, LEDC_TIMER_0, 0, LEDC_HPOINT_HSCH1_S};

//    ESP_ERROR_CHECK(ledc_timer_config(&buzzer_timer));
//    ESP_ERROR_CHECK(ledc_channel_config(&channel));

    // Test the buzzer.
//    ESP_LOGI(TAG, "Testing the buzzer");
//    set_buzzer_duty(512);
//    sleep(1);
//    set_buzzer_duty(0);
}

static void heimdall_setup_led(void)
{
    // Set up the RMT driver to control the LED
    ws2812_control_init();

    ESP_LOGI(TAG, "Testing the LED");

    struct led_state led;

    // Red
    led.leds[0] = 0xFF0000;
    ws2812_write_leds(led);
    vTaskDelay(500 / portTICK_PERIOD_MS);

    // Green
    led.leds[0] = 0x00FF00;
    ws2812_write_leds(led);
    vTaskDelay(500 / portTICK_PERIOD_MS);

    // Blue
    led.leds[0] = 0x0000FF;
    ws2812_write_leds(led);
    vTaskDelay(500 / portTICK_PERIOD_MS);

    // Off
    led.leds[0] = 0x000000;
    ws2812_write_leds(led);
}

static void heimdall_setup_ui_gpio(void)
{
    gpio_config_t io_conf;

    esp_err_t err;

    // Set up output GPIOs
    io_conf.intr_type = GPIO_INTR_DISABLE;
    io_conf.mode = GPIO_MODE_OUTPUT;

    io_conf.pin_bit_mask =  (1ULL << RELAY1_GPIO_PIN) |
                            (1ULL << RELAY2_GPIO_PIN) |
                            (1ULL << RELAY3_GPIO_PIN);

    io_conf.pull_down_en = 1;
    io_conf.pull_up_en = 0;

    ESP_ERROR_CHECK(gpio_config(&io_conf));

    // And set up input GPIOs
    io_conf.intr_type = GPIO_INTR_DISABLE;
    io_conf.mode = GPIO_MODE_INPUT;

    io_conf.pin_bit_mask =  (1ULL << TAMPER_SWITCH_GPIO_PIN);
    io_conf.pull_up_en = 0;

    ESP_ERROR_CHECK(gpio_config(&io_conf));

    heimdall_setup_buzzer();
    heimdall_setup_led();
}


static void heimdall_get_param(nvs_handle_t nvs, char *name, char **value)
{
    size_t required_len;

    ESP_ERROR_CHECK(nvs_get_str(nvs, name, NULL, &required_len));

    *value = malloc(required_len);
    assert(value != NULL);

    ESP_ERROR_CHECK(nvs_get_str(nvs, name, *value, &required_len));
}


static void heimdall_setup_badge_scans_file(void)
{
    esp_err_t ret;
#if 0
    // We don't build the BSP (Board Support Package) with long filenames,
    // so we're limited to MS-DOS style 8.3.
    const char * const BADGE_SCANS_FILENAME = "/spiflash/heimdall.txt";

    wl_handle_t wl_handle;
    FILE *f;

    esp_vfs_fat_mount_config_t mntconf = {
        .max_files = 8,
        .format_if_mount_failed = true,
        .allocation_unit_size = CONFIG_WL_SECTOR_SIZE,
    };

    // Note: this function is marked in the docs as for examples. I'm using
    // it here because it does exactly what we want, but I suppose it might
    // go away in future.
    ret = esp_vfs_fat_spiflash_mount("/spiflash", "mslfat", &mntconf, &wl_handle);
    ESP_ERROR_CHECK(ret);

    f = fopen(BADGE_SCANS_FILENAME, "r+");
    if (f == NULL) {
        ESP_LOGI(TAG, "Failed to open %s -- trying to create it", BADGE_SCANS_FILENAME);
        f = fopen(BADGE_SCANS_FILENAME, "w+");
        if (f == NULL) {
            ESP_LOGE(TAG, "Failed to create %s -- not caching badge scans to permament storage", BADGE_SCANS_FILENAME);
        }
    }
#endif
    // TODO
}

extern EventGroupHandle_t httpEventGroup;

void app_main(void)
{
    esp_err_t ret;
    nvs_handle_t nvs;
    size_t required_len;

    esp_log_level_set("wifi", ESP_LOG_WARN);

    ret = nvs_flash_init();
    if (ret == ESP_ERR_NVS_NO_FREE_PAGES || ret == ESP_ERR_NOT_FOUND) {
        ESP_ERROR_CHECK(ret);
    }

    ESP_ERROR_CHECK(nvs_open("heimdall", NVS_READWRITE, &nvs));

    heimdall_get_param(nvs, "wifi_ssid", &wifi_ssid);
    heimdall_get_param(nvs, "wifi_password", &wifi_password);
    heimdall_get_param(nvs, "heimdall_host", &heimdall_host);
    heimdall_get_param(nvs, "reader_api_key", &reader_api_key);
    heimdall_get_param(nvs, "writer_api_key", &writer_api_key);

    ESP_ERROR_CHECK(nvs_get_blob(nvs, "tag_key", NULL, &required_len));

    tag_key = malloc(required_len + 1);
    assert(tag_key != NULL);

    ESP_ERROR_CHECK(nvs_get_blob(nvs, "tag_key", tag_key, &required_len));
    tag_key[required_len] = 0;

    nvs_close(nvs);

  //  heimdall_setup_wifi(wifi_ssid, wifi_password);

    heimdall_setup_badge_scans_file();
    heimdall_setup_ui_gpio();

    httpEventGroup = xEventGroupCreate();

 //   heimdall_setup_websocket();

    BaseType_t rtret;
//    rtret = xTaskCreate(&access_list_fetcher_thread, "access_list_fetcher", 4096, NULL, 5, NULL);
//    if (rtret != pdPASS) {
//        ESP_LOGE(TAG, "Failed to create access list fetcher thread: %d", rtret);
//        assert(0);
//    }

    rtret = xTaskCreate(&tag_reader, "tag_reader", 4096, NULL, 5, NULL);
    if (rtret != pdPASS)
    {
        ESP_LOGE(TAG, "Failed to create tag reader thread: %d", rtret);
        assert(0);
    }
}

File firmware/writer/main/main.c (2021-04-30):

/*
 * Copyright (C) 2020 Rebecca Cran <rebecca@bsdio.com>.
 *
 */

#include <string.h>
#include <unistd.h>
#include <stdio.h>

#include <freertos/FreeRTOS.h>
#include <freertos/task.h>
#include <freertos/event_groups.h>

#include <cJSON.h>
#include <esp_system.h>
#include <esp_event.h>
#include <nvs_flash.h>
#include <esp_log.h>

#include <esp_vfs_fat.h>
#include <diskio_wl.h>
#include <esp_vfs.h>

/* Littlevgl specific */
#include "lvgl.h"
#include "lvgl_helpers.h"

#include "clrc663.h"
#include "iso14443.h"
#include "mifare_classic.h"
#include "network.h"
#include "tag.h"

static const char* TAG = "heimdall";

#define LV_TICK_PERIOD_MS 1

const int RFID_CS_GPIO_PIN = 32;
const int CAM_CS_GPIO_PIN = 15;

extern char *heimdall_host;
extern char *reader_api_key;
extern char *writer_api_key;

char *tag_key = NULL;

char *org_name = NULL;

extern char *wifi_ssid;
extern char *wifi_password;


static void heimdall_get_param(nvs_handle_t nvs, char *name, char **value)
{
    size_t required_len;

    ESP_ERROR_CHECK(nvs_get_str(nvs, name, NULL, &required_len));

    *value = malloc(required_len);
    assert(value != NULL);

    ESP_ERROR_CHECK(nvs_get_str(nvs, name, *value, &required_len));
}

/*****************************************
 *
 * Adapted from https://github.com/lvgl/lv_port_esp32/blob/master/main/main.c
 *
 *****************************************/

static void create_demo_application(void);

static void lv_tick_task(void *arg) {
    (void) arg;

    lv_tick_inc(LV_TICK_PERIOD_MS);
}

/* Creates a semaphore to handle concurrent call to lvgl stuff
 * If you wish to call *any* lvgl function from other threads/tasks
 * you should lock on the very same semaphore! */
SemaphoreHandle_t xGuiSemaphore;

static void guiTask(void *pvParameter)
{
    (void) pvParameter;
    xGuiSemaphore = xSemaphoreCreateMutex();

    lv_init();

    /* Initialize SPI or I2C bus used by the drivers */
    lvgl_driver_init();

    /* Use double buffered when not working with monochrome displays */
    static lv_color_t buf1[DISP_BUF_SIZE];
    static lv_color_t buf2[DISP_BUF_SIZE];

    static lv_disp_buf_t disp_buf;
    uint32_t size_in_px = DISP_BUF_SIZE;

    /* Initialize the working buffer */
    lv_disp_buf_init(&disp_buf, buf1, buf2, size_in_px);

    lv_disp_drv_t disp_drv;
    lv_disp_drv_init(&disp_drv);
    disp_drv.flush_cb = disp_driver_flush;

    disp_drv.buffer = &disp_buf;
    lv_disp_drv_register(&disp_drv);

    /* Create and start a periodic timer interrupt to call lv_tick_inc */
    const esp_timer_create_args_t periodic_timer_args = {
        .callback = &lv_tick_task,
        .name = "periodic_gui"
    };
    esp_timer_handle_t periodic_timer;
    ESP_ERROR_CHECK(esp_timer_create(&periodic_timer_args, &periodic_timer));
    ESP_ERROR_CHECK(esp_timer_start_periodic(periodic_timer, LV_TICK_PERIOD_MS * 1000));

    /* Create the demo application */
    create_demo_application();

    while (1) {
        /* Delay 1 tick (assumes FreeRTOS tick is 10ms */
        vTaskDelay(pdMS_TO_TICKS(10));

        /* Try to take the semaphore, call lvgl related function on success */
        if (pdTRUE == xSemaphoreTake(xGuiSemaphore, portMAX_DELAY)) {
            lv_task_handler();
            xSemaphoreGive(xGuiSemaphore);
       }
    }

    /* A task should NEVER return */
    vTaskDelete(NULL);
}

lv_obj_t *card_uid_lbl;
lv_obj_t *status_lbl;
lv_obj_t *card_owner_lbl;

static void create_demo_application(void)
{
    /* Get the current screen  */
    lv_obj_t * scr = lv_disp_get_scr_act(NULL);

    /* Create a Label on the currently active screen */
    lv_obj_t *welcome_lbl = lv_label_create(scr, NULL);
    status_lbl =  lv_label_create(scr, NULL);
    card_uid_lbl = lv_label_create(scr, NULL);
    card_owner_lbl = lv_label_create(scr, NULL);

    char *txt = malloc(128);
    snprintf(txt, 128, "Welcome to %s's\nRFID Card Writer Application.", org_name);

    lv_label_set_text(status_lbl, "Initializing...");
    lv_label_set_text(card_uid_lbl, "");
    lv_label_set_text(card_owner_lbl, "");

    lv_label_set_text(welcome_lbl, txt);


    /* Align the Label to the center
     * NULL means align on parent (which is the screen now)
     * 0, 0 at the end means an x, y offset after alignment */

    lv_obj_align(welcome_lbl, NULL, LV_ALIGN_IN_TOP_MID, 0, 0);
    lv_obj_align(status_lbl, NULL, LV_ALIGN_IN_LEFT_MID, 0, -40);
    lv_obj_align(card_uid_lbl, NULL, LV_ALIGN_IN_LEFT_MID, 20, 10);
    lv_obj_align(card_owner_lbl, NULL, LV_ALIGN_IN_LEFT_MID, 20, 80);

    free(txt);
}

void welcome_text(void)
{
    lv_label_set_text(status_lbl, "Please swipe new tag to program.");
    lv_label_set_text(card_uid_lbl, "Card UID: ");
    lv_label_set_text(card_owner_lbl, "Name: ");
}

void update_uuid_lbl(const char *new_uuid)
{
    char lbl_txt[128];
    char *uu;

    char *last_chars;

    uu = calloc(strlen(new_uuid) + 1, 1);

    memcpy(uu, new_uuid, strlen(new_uuid));

    last_chars = strrchr(uu, '-');
    if (last_chars != 0) {
        last_chars[0] = '\0';
        last_chars++;
    }

    sprintf(lbl_txt, "Card UUID:\n%s-\n%s", uu, last_chars);

    lv_label_set_text(card_uid_lbl, lbl_txt);

    free(uu);
}

void update_name_lbl(const char *txt, bool success)
{
    char lbl_txt[128];

    if (success) {
        sprintf(lbl_txt, "Name: %s", txt);
    }
    else
    {
        sprintf(lbl_txt, "Error: %s", txt);
    }

    lv_label_set_text(card_owner_lbl, lbl_txt);
}

void update_status_lbl(const char *txt)
{
    lv_label_set_text(status_lbl, txt);
}

extern EventGroupHandle_t httpEventGroup;
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

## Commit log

2020-05-09 rails new heimdall --skip-keeps --skip-turbolinks --skip-test --skip-system-test --skip-spring
2020-05-09 nuke webpacker
    if we do a proper frontend at some point, I want to have control
    over how the JS is built and packed. use sprockets for now for the
    only thing that needs it (which is activeadmin).
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2020-05-09 allow filtering certification issuances by issued_at date
2020-05-11 several changes
    - add API token viewing and regeneration to badge readers
    - track when an API token was last rengerated and don't store the
    API token in paper trail logs
    - add restricted_access to badge readers (prevents memberhsip access,
    good for staff closets etc.)
    - move certification_instructors and badge_reader_certifications to
    be select lists in the certification and badge forms, respectively,
    instead of separate admin pages and panels
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2020-05-16 add stripe synchronization service
    StripeSynchronizationService creates local users for all users
    we know about in the configured Stripe account and updates any
    local users with info about their subscription. it has to be run
    via `StripeSynchronizationService.sync_all_users_now` from a
    rails console for now; soon there will be a Stripe webhook endpoint
    that will synchronize users whenever subscription changes happen.
2020-05-17 add an admin page for delayed jobs
    useful for debugging purposes, and potentially useful to see if
    there is a sync in progress in case someone's wondering why a new
    user hasn't shown up yet
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2020-05-24 add an API for badge writers to use to program badges
    it takes a `badge_token` param, sets it onto the user it's
    currently set to program, if any, and then returns JSON blob that
    includes the user's name, or a JSON blob with a key called
    `status` whose value is `not_programming` if the badge reader isn't
    set to program a badge for a user right now.
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2020-05-24 add a skeleton api to fetch badge tokens accessible by a given reader
    right now it returns all badge tokens in the system, effectively
    allowing access to anyone with a badge. the logic to limit the
    badge tokens to only users who should be allowed to access the
    badge reader in question is yet to come.
    also prevent multiple users from sharing the same badge token;
    that's not something that should happen in practice since they
    will be randomly generated, but prevent against it happening
    just in case.
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2020-05-30 Backend: misc fixes. Added UserFeedback class for LEDs, buzzer & LCD
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2020-06-01 store a badge's id, token, and authorized status on scan
    the id is a string burned into every badge. it's not secure to use
    as authentication material because someone could lift someone
    else's badge id by walking near them and then build a device that
    acts like a badge with that id, so we continue to use the badge
    token to perform authentication - but it's useful information to
    have if someone is failing to scan in repeatedly and we're not
    sure why.
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2020-06-11 Backend: various improvements
    - Add pi-rc522 as a subrepo. We can't use the version from pypi because
    it unconditionally tries to reconfigure the pin naming scheme.
    - Add a note to README.md about fake/clone RC522 boards that might not
    work correctly.
    - Add dunders.
    - Handle SIGINT/Ctrl-C and exit gracefully.
    - Use the logging module for debug/verbose/warning/etc. messages.
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2020-06-25 Backend: update README for the ESP32-based development environment.
    Also, switch to ESP-IDF version 4.1, and update the code to match.
    [nvs_cfg.csv, nvs_data.csv]
2020-06-25 Backend: Update README to reflect swap to ESP32
2020-06-30 Backend: fix formatting and move rc663 init to clrc663.c
    [clrc663.c, main.c]
2020-07-20 Add outside board schematics and update reader code.
    [heimdall_outsideboard.kicad_pcb, heimdall_outsideboard.sch, partitions.csv]
2020-07-20 Rename schematics directory to boards, and rename inside board directory
    [heimdall_outsideboard.kicad_pcb, heimdall_outsideboard.sch]
2020-07-20 Annotate outside board, change paper layout and bump rev to 0.2.
    [heimdall_outsideboard.sch]
2020-07-21 Update outside board design with initial PCB layout
    [heimdall_outsideboard.kicad_pcb, heimdall_outsideboard.sch]
2020-07-21 Outside board design: more PCB layout
    [heimdall_outsideboard.kicad_pcb]
2020-07-21 Outside board: replace the pin headers with screw terminals
    [heimdall_outsideboard.kicad_pcb, heimdall_outsideboard.sch]
2020-07-21 Revert "Outside board: replace the pin headers with screw terminals"
    This reverts commit 695c30ad44e01b6420bbd27eb88eba567c36bb63.
    [heimdall_outsideboard.kicad_pcb, heimdall_outsideboard.sch]
2020-07-21 More outside board PCB layout.
    [heimdall_outsideboard.kicad_pcb]
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2020-07-23 Add the inside board schematic and board layout
    This board was ordered on Monday, July 20, 2020. We'll see how it
    turns out...
    Also, for posterity's sake: we placed the order through PCBWay:
    https://pcbway.com
    [heimdall_insideboard.kicad_pcb, heimdall_insideboard.sch]
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2020-07-23 Update outside board schematics and board layout
    [heimdall_outsideboard.kicad_pcb, heimdall_outsideboard.sch]
2020-07-25 Update outside board to rev 01 and add Gerber files and BOM.
    [heimdall_outsideboard-B_Cu.gbr, heimdall_outsideboard-B_Fab.gbr, heimdall_outsideboard-B_Mask.gbr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]
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2020-07-26 bugfix: reload before reporting a badge reader as opened
    this fixes a situation where the first open report for a new
    badge reader would blow up - the reason being that action cable
    keeps a persistent reference to the BadgeReader around as the
    connection's identifier and doesn't reload it before handling any
    messages sent by the client, so when we call report_manually_opened!,
    the badge reader doesn't have its last_manual_open_requested_at
    populated - and so the `.max` fails because the nil value can't be
    compared with the `Time.now` timestamp.
2020-07-30 Update backend code with many fixes and improvements.
    [nvs_cfg.csv, nvs_data.csv, partitions.csv]
2020-08-02 Backend: reorganize layout to accommodate the writer firmware.
    [nvs_data.csv]
2020-08-25 Various backend updates
    [nvs_data.csv]
2020-08-30 Backend: fix GPIO assignments
    [access.c, clrc663.c, main.c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]
2020-08-31 Backend: add code to test the relays, buzzer and led and fix mifare code
    The MIFARE code was causing a load exception trying to read the UID.
    Fix it by allocating the memory up-front and just memsetting it between
    tags.
    [iso14443.c, main.c, tag.c]
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2020-09-13 Backend: move the RFID Writer to the ESP-WROVER-KIT and add LCD code
    [nvs_cfg.csv, nvs_data.csv]
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2020-09-20 bump rails to 6.0.3.3 for security fixes
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2020-11-02 Backend: complete basic functionality for the RFID writer code
    [nvs_data.csv, nvs_data_template.csv]
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2020-11-07 bugfix: check profile attachment status before rendering in form
2020-11-15 Backend: fix the RFID reader and writer code.
    [main.c, tag.c]
2020-11-15 Update outside board schematics and layout to revision 2
    [heimdall_outsideboard-B_Cu.gbr, heimdall_outsideboard-B_Fab.gbr, heimdall_outsideboard-B_Mask.gbr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]
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2020-11-21 Backend: switch to my fork of esp32-uuid and update lv_port_esp32
    The upstream esp32-uuid repo doesn't contain CMakeLists.txt, which is needed in
    newer version of ESP-IDF to recognize the directory as a component.
    Switch to my fork and branch of esp32-uuid to fix the build.
    Also, update to a newer revision of the lv_port_esp32 submodule.
2020-11-29 Backend: fix connecting to the production instance
    Also, regenerate sdkconfig after switching to the 4.2-rc tag and
    updating lvgl.
2020-12-23 Backend: Update code to work with the Adafruit Featherwing board
    [partitions.csv]
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2021-01-15 sync waivers immediately into heimdall the moment they're signed
    waivers will now be pushed into heimdall in response to a webhook
    push. note that the webhook will need to be added manually to each
    template's settings; make salt lake only has one waiver template,
    so that's easy enough to do.
    and, now that that's the case, revert back to doing a full waiver
    import weekly instead of daily (which hopefully won't find any
    changes).
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2021-01-28 whoops, missed a few uses of `subscription.plan`. also i think i know what's up
    it looks like the one user who's running into this has multiple plans on
    their subscription for some reason. i think stripe returns an
    empty plan when we ask for *the* plan in such a case because there
    are multiple, so it wouldn't be accurate to pick just one.
    how to handle this is an open question - combining the two might
    be the right approach, or treating each pricing as its own
    subscription, or adding a additional model for pricings. (we don't
    want to go too far off the beaten path if the information isn't
    actually useful for heimdall though.)
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2021-03-18 move backend/ into the newly created future/
    [nvs_cfg.csv, nvs_data_template.csv, partitions.csv]
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2021-03-22 update the inside board PCB design file
    a number of changes:
    - add an extra terminal to the wiegand header for the 26/34 mode
    switching pin that most wiegand readers have, complete with a
    jumper to selectively connect that terminal to ground
    - expand screw terminal silkscreen outline to fit the actual size
    of the screw terminals; i misread the datasheet when laying them
    out in the previous board revision
    - move the 5v regulator .2" to the right so that there's more
    clearance between it and the 3.3v one when the heatsinks are
    attached
    - correspondingly, move the ESP32 left by about .1" to make room
    for the tamper switch screw terminal's actual size
    - move neighborin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
    [heimdall_insideboard.kicad_pcb, heimdall_insideboard.sch]
2021-04-01 inside board version 3
    - add a 3.3v -> 5v level shifting circuit to the addressable RGB
    LED's input. it seems to work without it in my testing of board
    version 2, but I'd rather not find out the hard way that it works
    for some LEDs but not for others since it's out of spec for what
    they're supposed to require, which is 0.7*VCC = 3.5v for logic
    level high signals.
    - a handful of vias were underneath where the voltage regulator
    heat sinks go. to prevent the heatsinks from coming in contact
    with them, move them outside of the heat sinks' footprint.
    [heimdall_insideboard.kicad_pcb, heimdall_insideboard.sch]
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2021-04-10 reorganize project directories
    rename `boards` to `hardware`, move `boards/outside_board` to
    `future/hardware/outside_board`, and rename `future/backend` to
    `future/firmware`
    [heimdall_insideboard.kicad_pcb, heimdall_insideboard.sch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]
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2021-08-06 future/firmware: Various updates and fixes
    - Set the hostname to heimdall-esp32-<macaddress> - this should be more
    useful than the generic `espressif` hostname.
    - Set the project version to 0.5.0.
    - Update sdkconfig for ESP-IDF v4.3
    [nvs_data_template.csv]
2021-08-14 Fix future/firmware/writer to work with ESP-IDF v4.3
    [clrc663.c, tag.c]
2021-09-18 Update heimdall_insideboard.sch with version from Steven Hildebrand
    Steven Hildebrand has improved the layout of the inside board schematic
    to avoid overlapping text and symbols.
    [heimdall_insideboard.sch]
2022-09-12 Update sdkconfig files for ESP-IDF v4.4.2 and fix LED timing values
    The NeoPixel doesn't work with the default timings (likely due to WiFi),
    so downgrade them to the WS2811 values, which it's compatible with.
2022-09-12 Update future/hardware/outside_board for KiCad 6 and newest design
    Update the files to KiCad 6 format.
    Update schematic/pcb for the latest revision of the board that was sent
    to Aisler for manufacturing and assembly.
    [heimdall_outsideboard-B_Cu.gbr, heimdall_outsideboard-B_Fab.gbr, heimdall_outsideboard-B_Mask.gbr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]
2025-10-26 RFID Reader PCB (and other KiCAD updates) (#64)
    * Created an RFID antenna and CLRC663 PCB
    * Performed some cleanup of the KiCAD files
    [43045-1019.stp, 53398-1071.stp, CLRC66303HNY.stp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]
2025-12-04 Cleanup repo wrt future directory
    Delete the Arduino firmware project/code and the schematics under
    future/hardware. Move future/firmware back to the top level.
    [heimdall_outsideboard.csv, heimdall_outsideboard.kicad_pcb, heimdall_outsideboard.kicad_sch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]
2026-01-07 Outside Board - RFID Reader with RS232 (#69)
    Updated the reader PCB to use RS232 communication via an RJ12 connector
    [1991095.stp, CRJ024-1-TH.stp, Reader v0.1.step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]
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2026-03-09 Fixing beeper nets on reader board (#71)
    [reader.kicad_pcb, reader.kicad_sch]
2026-03-23 Relay Board - Ready for fab (#72)
    Here's the first version of the relay board we sent to fab
    [1759017.stp, 1759033.stp, 1759059.stp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]

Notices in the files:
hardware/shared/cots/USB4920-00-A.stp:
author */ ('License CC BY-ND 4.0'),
